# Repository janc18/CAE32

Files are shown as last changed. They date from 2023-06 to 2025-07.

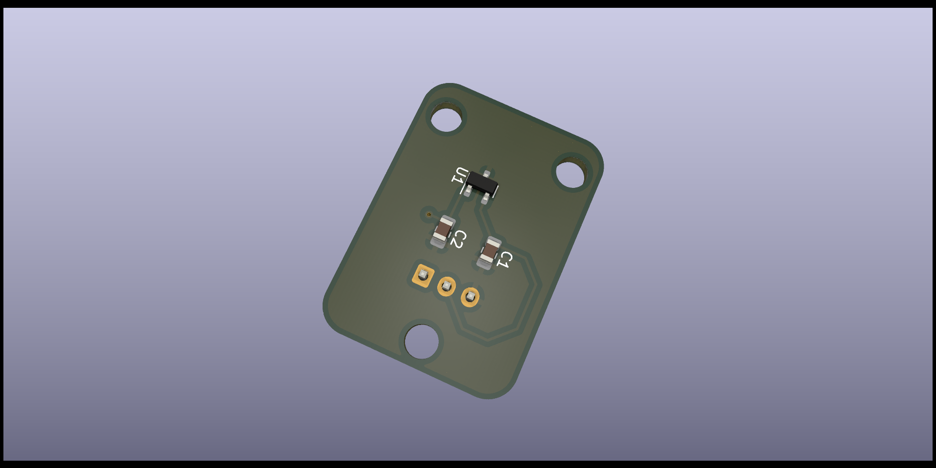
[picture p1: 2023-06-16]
Schematics/CAE32_PCB/Hall_PCB/hall_pcb.png

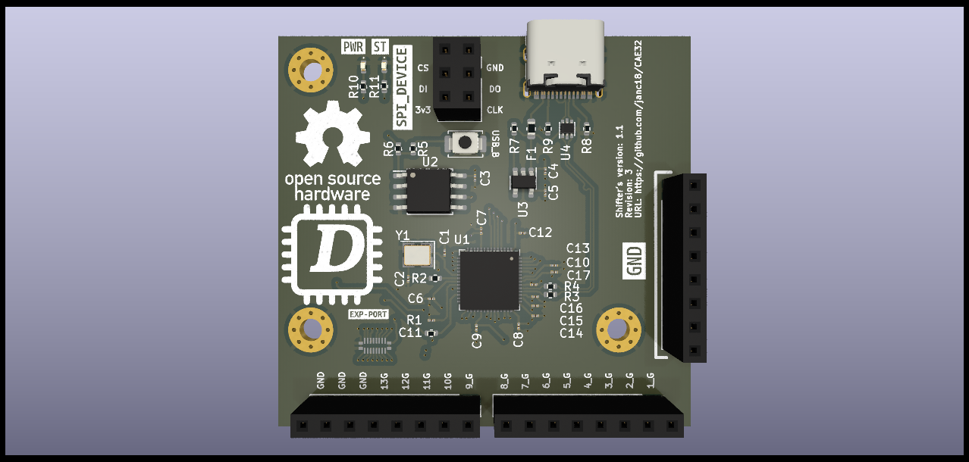
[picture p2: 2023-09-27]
Schematics/CAE32_PCB/Shifter/Shifter.png

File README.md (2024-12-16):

# CAE32

CAE32 is a project for building and developing all stages of a gaming wheel for PC, specifically for the GNU/Linux operating system.

If you want to contribute, please read the [CONTRIBUTING-english.md](./docs/CONTRIBUTING-english.md) file.

Si tu quieres contribuir, por favor lee el documento [CONTRIBUTING.md](./CONTRIBUTING.md)  

## Overall current status

Developing the UML diagram of the whole system

### PCBs







### Firmware

Working on the development of the UML diagram for the pedals  firmware

### Software

Needed the improvement of compilation and flags for the user interface

## The stages include:

* PCB Design
* Firmware
* Driver (Kernel module if necessary)
* Configuration and calibration through a graphical user interface (GTK-3)
* Design of mechanisms for pedals, gear lever, and wheel
* Power PCB design for feedback motor control (FFB)

### PCB Sponsored by PCBWay



The PCB quality is excellent, the contact with the support service is good, they responded very quickly in the case of any issue, 
and it has a good PCB finish using the STM assembly service,  all the IC pads are correctly soldered. Overall, the total cost of 5 PCBs 
and 2 PCBs with the assembly service is a very accessible, so I will keep using PCBWAY to build the next PCB iterations

[PCBWay Webpage](https://www.pcbway.com/)

## Programming Frameworks and Tools

* Espressif (ESP-IDF)
* STM32CubeIDE
* STM32CubeProgrammer

### User Interface

The interface is developed with the GTK 3 framework, which will allow configurations such as:

* Visualization of data graphically and textually (console)
* Transmission type (Manual, Automatic, Sequential, custom) **Natively**
* Pedal limits, sensitivity
* Pedal type
  * Analog input (Potentiometer, Hall effect, and load cell)
  * SPI, I2C input (Custom sensor)
* Firmware update

## How to compile the project

1. Install all the dependencies
```bash
sudo apt install cmake make gcc pkgconf libevdev-dev libgtk-3-dev libgtk-3-0 libgtest-dev g++
```

2. Run the script to check if all the dependencies was successfully installed
```bash
./Source_code/checking_dependency.sh
```
3. Execute the Makefile to build the graphic interface and the unit tests
```sh
make -C Source_code/
```

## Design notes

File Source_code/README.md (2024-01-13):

# Code // Codigo

In this folder, you can find the entire project code, which can be built by executing:

```sh 
make
```

*Now, a brief explanation of the files and folder content*

## config_file

File necessary to build all the documentation using the _Sphinx_ programm

## checking_dependency.sh 

A small bash script to check if all the dependencies are already installed, in case
someone isn't installed, it will print what is missing.

## Shared_libraries/

Files shared between the Firmare, TESTs, and Device_simulation folders for quick 
access and modifications.

## Desktop_files/

A bash script to execute when the GUI is select in the system menu

## Firmare/

Firmware for the modules(Pedals, shifter and steering wheel) and main board.

## Interfaz_grafica/

GUI(GTK) Source code 

## TESTs/

GUI and Device simulation unit tests

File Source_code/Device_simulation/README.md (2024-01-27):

# Device Simulation

In this section, you will find the resources required to build executables for simulating hardware.

# Steps to build a joystick simulation device

1. Create a build directory at src/
```sh
mkdir src/build 
```
2. Move to that directory
```sh
cd src/build
```

3. Build executable
```sh 
cmake ..
make
```

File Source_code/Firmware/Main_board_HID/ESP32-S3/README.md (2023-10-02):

# ESP32-S3
This is the source code for the main microcontroller, and it performs the following tasks:

- Communication with the host (PC), connecting via a USB cable and appearing in the system as an HID device (Joystick).

- Collection of all data from the modules, such as their position and status, through SPI communication.

- Firmware updates for modules via SPI, thus avoiding the use of firmware programmers for the module.

## Steps for Building the Project (in case you're not using the Docker container)

1. Install ESP-IDF.

2. In this directory, execute the following commands:

```sh
get-idf
idf.py build
```

3. Upload the new firmware.

## SPI Register for each module

### Pedals

|Command (HEX)|Name|Detalles|
|-|-|-|
|0x01|VERSION|Installed Firmware Version|
|0x02|CONFIG_RESOLUTION|Configure ADC Resolution|
|0x03|ACCE|Accelerator Value|
|0x04|BRAKE|Brake Value|
|0x05|CLUTCH|Clutch Value|
|0x06|STATUS|Error Status|

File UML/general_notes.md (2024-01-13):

# Change log PCB Pedals

## Issues
* Fix silkscreen text at UART port TX->RX RX->TX *Done*
* Change diameter pcb holes for M3 *Done*
* Route correctly the boot and reset buttons, and search for a small factor buttons *Done*
* Change communication connectors for a FCP connector *Done*
* Round pcb corners *Done*
* Change the female headers for block connectors or quick access connectors(Changed to screw terminals) *Done*
* The IC ADC require extra components at his inputs(added low pass filters) *Done*

## PCB Testing behavior

- Check the noise and data acquisition time without a single pole filter

## TDD(Test Driven Development)

To know if the GUI it's working correctly, one way, can be tested with the use of a virtual device than can be created with the 
uhid library for the linux system, the functionalities that could be tested will be the next:

- Device detection (Connection)
- Device descriptor
- Visual representation (axis and steering wheel)
- Emulation of device console(sending and reciving data for configuration behavior)

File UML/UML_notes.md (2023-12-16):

# Packages

- UI
  - UI Updater
  - Status console
  - Firmware Updater::Stm cube programmer
  - Data values display
  - Configuration pcb values(soft stops, hard stops, sensibility, etc)

- Devices configuration
    - Steering wheel configuration
      - Serial terminal
    - Pedals configuration
      - Serial terminal
    - Shifter configuration 
      - Serial terminal
  
_With the Serial terminal it's posible to send values witout the necessity of firmware update_

- Hardware(PCBs)
    - Steering wheel
    - Pedals
    - Shifter

# Use cases diagram

- Hardware
- USB
- HID
- Game
- UI

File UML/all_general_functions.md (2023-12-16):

# General functions overview 

## GUI(GTK)

* Representation in real time of the input (pedals, shifter, etc.) generated by the user 
* Easy configuration of the devices
* Console for displaying information
* Firmware update and upload
* GUI update
* Verification of software dependencies (STM32CubeProgrammer) bin path selection
* Information about the program

## Pedals 

*Note 1: for some cases is implied to use a serial terminal*

*Note 2: some function depends of other sources like config files founded at PC(Linux system)*

- Get analog readings
  - Serial data communication with ADC chip
    - initial IC configuration (Resolution, speed, one shot,etc)
    - *Get data*
  - getting the data stream from the load cell IC 
    - Configure a pwm channel to generate the clock signal
    - *Get data*

- Compact or mergue all the data for usb HID protocol
  * After the analog readings send the usb data stream

- Load pre-configuration using the dip switch 
  * if it's not posible to load a new configuration to the pcb because it's imposible to access to the GUI it will have some profiles pre-loaded

- HID device descriptor
  - 3 to 11 channels
  - 14 bits each
  - serial terminal for pcb status and configuration
  - bit stream for configuration *optional*

- PCB Status
  - Check if ICs ADC and load cell function correctly _serial terminal_
  - show the status with the serial terminal and leds

- apply filter to any analog signal
  * before sending the data, it will apply a function to modify the raw values to apply a filter(low filter, high filter)
  *Note: this will be generated by the GUI and sended by the serial terminal*

- Calibration functions

  _Note 1: This process will be guide graphical by the GUI, if the GUI isn't available then can be Configure with the serial terminal_
  
  - choose the start and stop position
  - sensibility
  - select what pedal correspond to certain input

- UI config file (.txt | .config | .cae32) *Founded in the Linux system*

- add function to check system stability (low resorces or not enough speed, etc)

- all task or functions need to return finish status (SUCCESS, ERROR, [custom errors messages])

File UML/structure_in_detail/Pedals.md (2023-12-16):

# Draft structure of functions 

This is a firmware draft of how can be develop the code for the pedals.

This file will include the posible functions, struct, enums that will be used for the UML diagram

## Tasks (FreeRTOS)

- StatusMonitorTask
- IcAdcReading
- LoadCellDataAdquisition
- SendingUsbPackage
- SerialTerminalInUsbData
- SerialTerminalOutUsbData
- ApplyAdcFilter
- ShowLedStatus
- LoadProfile (use an interruption in the case of any change at switches states)

## Functions
- SetConfigValues (set, top and low limits, inverted axis)
- GetConfigValues (get, top and low limits, inverted axis)
- LoadProfile (Load all the values from the ROM)
- CreateProfile
  - Save the limits and what function do every channel, example(ADC channel 1 its the brake,Load cell 1 is the clutch, etc.)
  - Depending of the dip switch state located at the pcb will save the already create profile in a different location to save until 7 profiles    
  - Save values at ROM
- ConfigUsbStream (depending of the profile select change the device descriptor)
- Reboot
- LimitsCalibration (With the GUI or serial terminal, pressing the pedal to define in real time the limits)
- ReadSwitchValue (Get the value depending of the 3 switch inputs) 
- ParserCommand (build a struct that can be used to modify values)  

## Enum

```c
typedef enum {
    TASK_SUCCESS,
    TASK_ERROR_GENERIC,
    TASK_ERROR_TIMEOUT
}TaskStatus;

typedef enum{
    INVALID_PARAMETER,

}err_t

typedef enum {
    ADC_CHANNEL_0,
    ADC_CHANNEL_1,
    ADC_CHANNEL_2,
    ADC_CHANNEL_3,
    ADC_CHANNEL_4,
    ADC_CHANNEL_5,
    ADC_CHANNEL_6,
    ADC_CHANNEL_7,
    LC_CHANNEL_1,
    LC_CHANNEL_2,
    LC_CHANNEL_3,
}Channel

```

## Structs

```c
typedef struct{
  void *funtion-to-execute-in-case-of-error;
  void *generic-function-to-text-through-serial-console;
  uint32 RetryCount;
  
}StatusTask;

/*
- The value correspond to the channel to use 
- Example
    - Clutch channel ADC 3 = Clutch=ADC_CHANNEL_3;
    - Throttle Load cell 1 = Throttle=LC_CHANNEL_1;
    - The channels than don't be use its value is = -1
    - All customs channels without use = Custom_0 = -1;
*/

typedef struct{
    char Throttle;
    char Clutch;
    char Brake;
    char Custom_0;
    char Custom_1;
    char Custom_2;
    char Custom_3;
    char Custom_4;
    char Custom_5;
    char Custom_6;
    char Custom_7;
    char Custom_8;
    char Custom_9;
}ChannelFunction;

typedef struct{

}LowPassFilterValues;

typedef struct{
    uint16 Low;
    uint16 Top;
    bool inverted;
}HardwareConfig

```

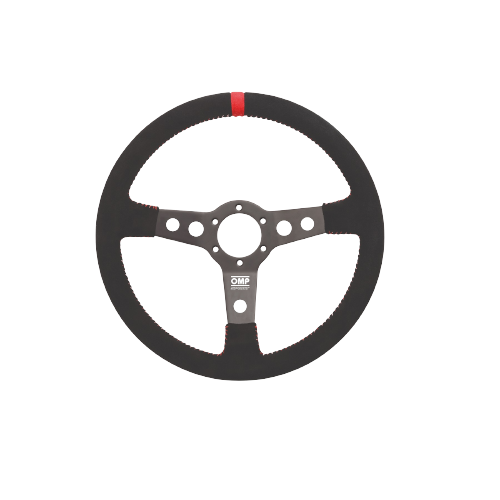
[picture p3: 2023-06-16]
Source_code/Interfaz_grafica/Interfaz_gtk/src_images/Volante3.png

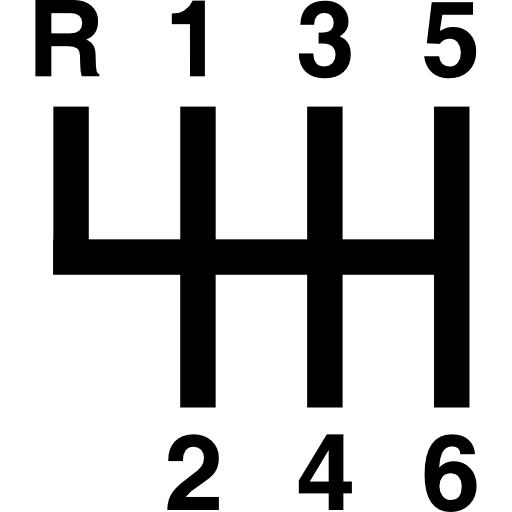
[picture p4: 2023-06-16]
Source_code/Interfaz_grafica/Interfaz_gtk/src_images/H.png

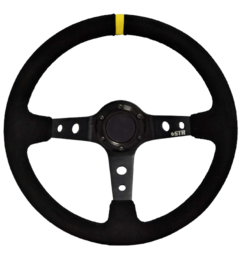
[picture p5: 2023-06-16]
Source_code/Interfaz_grafica/Interfaz_gtk/src_images/Volante3-1.png

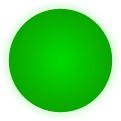
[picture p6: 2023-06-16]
Source_code/Interfaz_grafica/Interfaz_gtk/src_images/bitmap.png

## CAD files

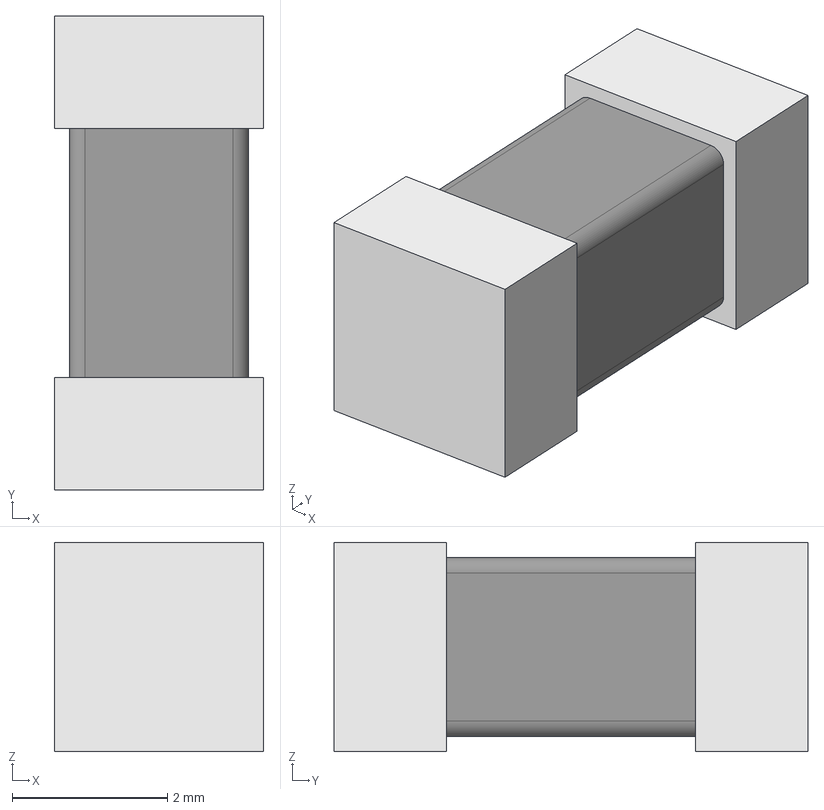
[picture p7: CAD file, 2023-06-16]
Schematics/CAE32_PCB/Disenos_de_componentes_electricos/Modelos3d/Freecad/fusible.FCStd
2.69 x 6.10 x 2.69 mm

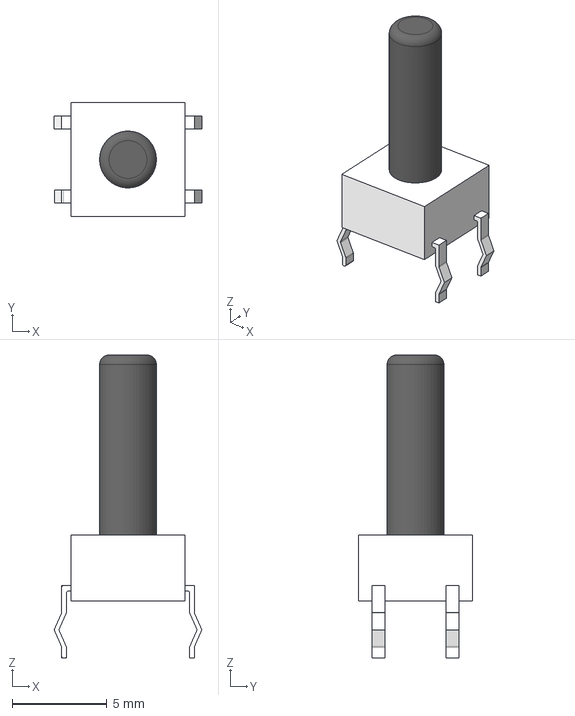
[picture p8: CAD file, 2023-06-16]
Schematics/CAE32_PCB/Pedals/3d Models/TS-1095PD-A16B2-D2.FCStd
7.80 x 6.00 x 16.0 mm

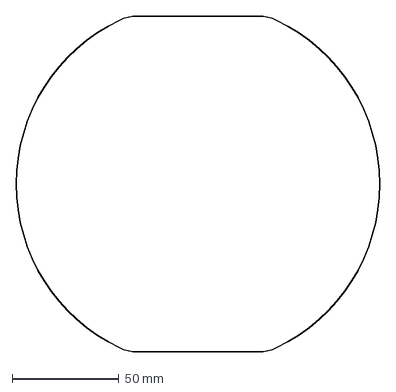
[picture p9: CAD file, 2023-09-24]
Schematics/CAE32_PCB/Steering_Wheel_FFB/3D_models/simcube.dxf
170.0 x 157.1 mm

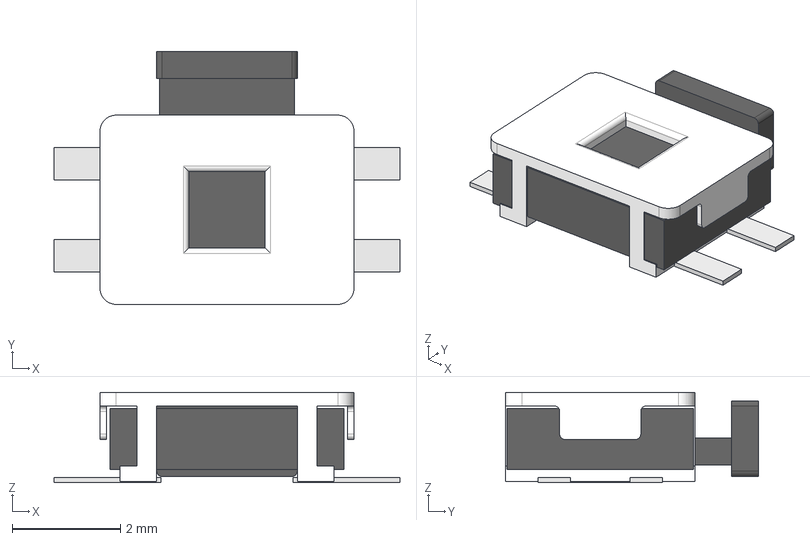
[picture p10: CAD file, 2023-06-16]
Schematics/Modelos_3D_Componentes_electricos/EVQPUM02K.FCStd
6.40 x 4.68 x 1.67 mm

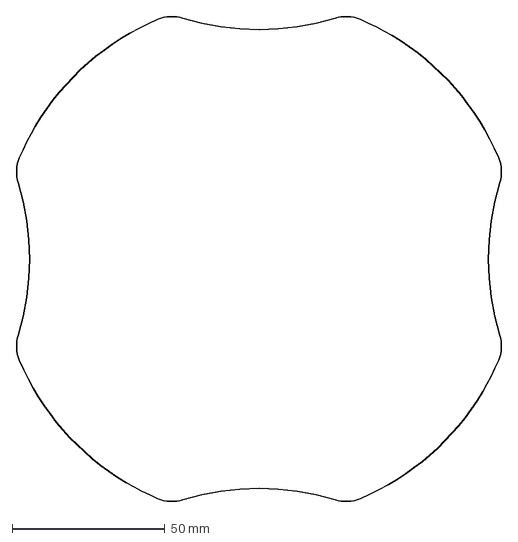
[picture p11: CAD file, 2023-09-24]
Schematics/CAE32_PCB/Steering_Wheel_FFB/3D_models/cutOutPcb-Shape2DView.dxf
158.6 x 158.6 mm

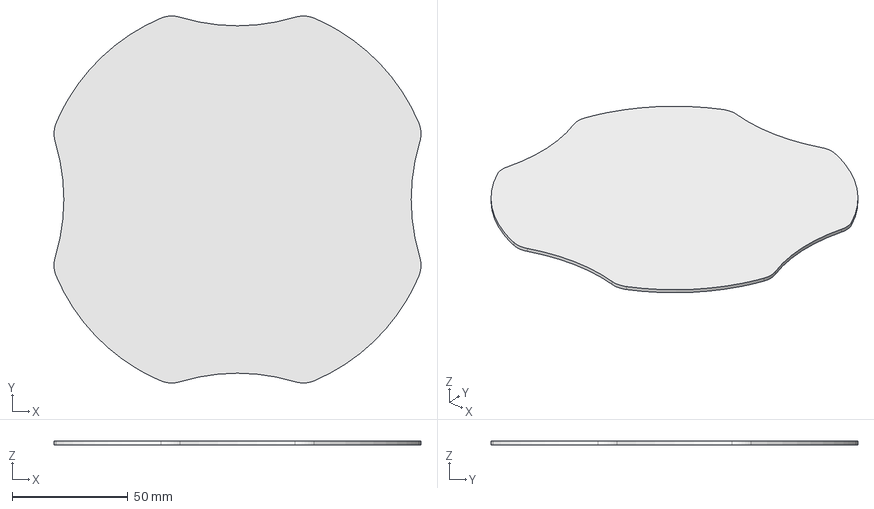
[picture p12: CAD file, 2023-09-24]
Schematics/CAE32_PCB/Steering_Wheel_FFB/3D_models/cutOutPcb.FCStd
158.5 x 158.5 x 1.60 mm

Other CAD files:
Schematics/CAE32_PCB/Hall_PCB/CutPcbLayout/edges.FCStd
Schematics/CAE32_PCB/Pedals/CutPcbLayout/layout.FCStd
Schematics/CAE32_PCB/Pedals/3d Models/TS-1095PD-A16B2-D2-Part.step
Schematics/Modelos_3D_Componentes_electricos/EVQPUM02K-Part.step

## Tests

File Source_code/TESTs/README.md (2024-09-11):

# Unit Tests

## Device descriptor tester

At the folder ```device_descriptor``` is the source code to check if the device descriptor
is correctly configured.

The executable can be found at ```device_descriptor/build/bin``` this is compile automatically
when you build the whole project (**Instructions at the main README**), 

## How it works
This executable needs an input file with all the information about the device to search, an 
example of this file can be found at ```device_descriptor/build/bin```, it requires a sudo 
permission to read the incoming data from the device.

This program is paired with another program, that program create a virtual device that 
simulates inputs and it's verify with the input file give (**Example at device_descriptor/build/bin**)

## TODO

- [ ] Input analysis (Virtual Device)
    - [x] Get the number of the Events
    - [ ] Allocate memory for each Event
    - [ ] Add each value to an array of Event
    - [ ] Get the step increment
    - [ ] Get from file the actuation range
    - [ ] Create a log than can be saved in a file
    - [ ] 

- [ ] Free resources (memory) when the device is desconnected
    - [ ] Know whe the device was disconnected

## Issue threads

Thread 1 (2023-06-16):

Crear un archivo docker

janc18, 2023-06-16:
Para que sea más sencillo realizar la construcción y pruebas unitarias, lo conveniente es crear un contenedor con todas las dependencias necesarias.

Para compilar

- Interfaz de usuario(GTK3)
- Firmware (ESP-IDF y "STM en el caso de que sea posible")

janc18, 2023-06-17:
Se añadió un archivo Docker con base de Debian Bullseye, referente a la construcción del firmware usando ESP-IDF, no es necesario debido a qué ya cuenta con una imagen oficial de Docker

Closed 2023-06-17.

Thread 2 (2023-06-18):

Crear tests para GUI y dispositivo

janc18, 2023-06-18:
Como buen software en desarrollo requiere de pruebas.

Para probar la GUI y el dispositivo HID, es posible crear un dispositivo virtual HID conocido como modulo uinput,  [aquí](https://github.com/janc18/CAE32/blob/main/Codigo/Device_simulation/src/uhid-HID.c) se encuentra un ejemplo.

Lo ideal es crear un Makefile, donde ejecute diferentes pruebas.

También sera necesario crear una versión de debug de la GUI, he incluso logs

Closed 2023-09-30.

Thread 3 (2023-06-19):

Calcular consumo de PCB

janc18, 2023-06-19:
Revisar en la hoja de datos de cada componte (IC's) su consumo(mAh) y anotarlo en el esquema eléctrico

janc18, 2023-06-20:
El consumo aproximado es:
|Componente|Consumo|Cantidad|
|-|-|-|
|MCU|120 mA|1|
|REF3033|50uA|1|
|ADC128S102|3.1mA|1|
|HX711|1500ua|3|

**Consumo total en primera revisión:128mA**

HUANGJIN169, 2023-09-01:
Very good. When will the direct drive PCB be updated?

janc18, 2023-09-03:
Hi, I haven't started yet the development of the Direct drive PCB, I just finished the Pedals PCB version 2 about two moths ago, but i haven't tested it yet, I need to get the PCB manufactured, assembly and firmware programming but I can't do it right now, tomorrow i will update the CAE32 docs with an English version, for now please give a check:https://cae32-docs.readthedocs.io/es/latest/

janc18, 2023-09-03:
Please review de Documentation,which is now available English.

HUANGJIN169, 2023-09-03:
Ok, thank you for your reply. I also look forward to your direct drive PCB

HUANGJIN169, 2023-09-13:
Hello, how can I contact you, such as Facebook or Twitter and no China WeChat?

janc18, 2023-09-13:
Hi @HUANGJIN169 , you can contact me through Discord. This is my username:eling.
But if you can't use Discord I can create a Twitter account

janc18, 2023-09-14:
Twitter account: ElingJAg

HUANGJIN169, 2023-09-15:
You can add my friend through Discord. My user name is:simracingos#6659

Closed 2023-09-04.

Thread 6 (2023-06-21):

Añadir serigrafía a la PCB

janc18, 2023-06-21:
Agregar la siguiente serigrafía a la PCB

* Símbolos de open hardware

* Easter egg

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

* Datos de PCB (URL de REPO, número de revisión, versión de PCB)

* Añadir nombres de puertos correspondientes (UART, CAN, SPI, etc.)

janc18, 2023-06-22:
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

Closed 2023-06-22.

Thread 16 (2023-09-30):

Redesign the Shifter PCB

janc18, 2023-09-30:
To meet standard features without incurring extra costs from the PCB manufacturer

HUANGJIN169, 2023-09-30:
very good

janc18, 2023-10-01:
# Change-log *Shifter_PCB_v1.2.1*

- Replace the Pin Headers for FCP connectors
- Changed via diameter from 0.15 to 0.3mm
- Changed BOOT button position
- Replace all the GND Pin Headers for just 3 Pin Sockets

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

Closed 2023-10-01.

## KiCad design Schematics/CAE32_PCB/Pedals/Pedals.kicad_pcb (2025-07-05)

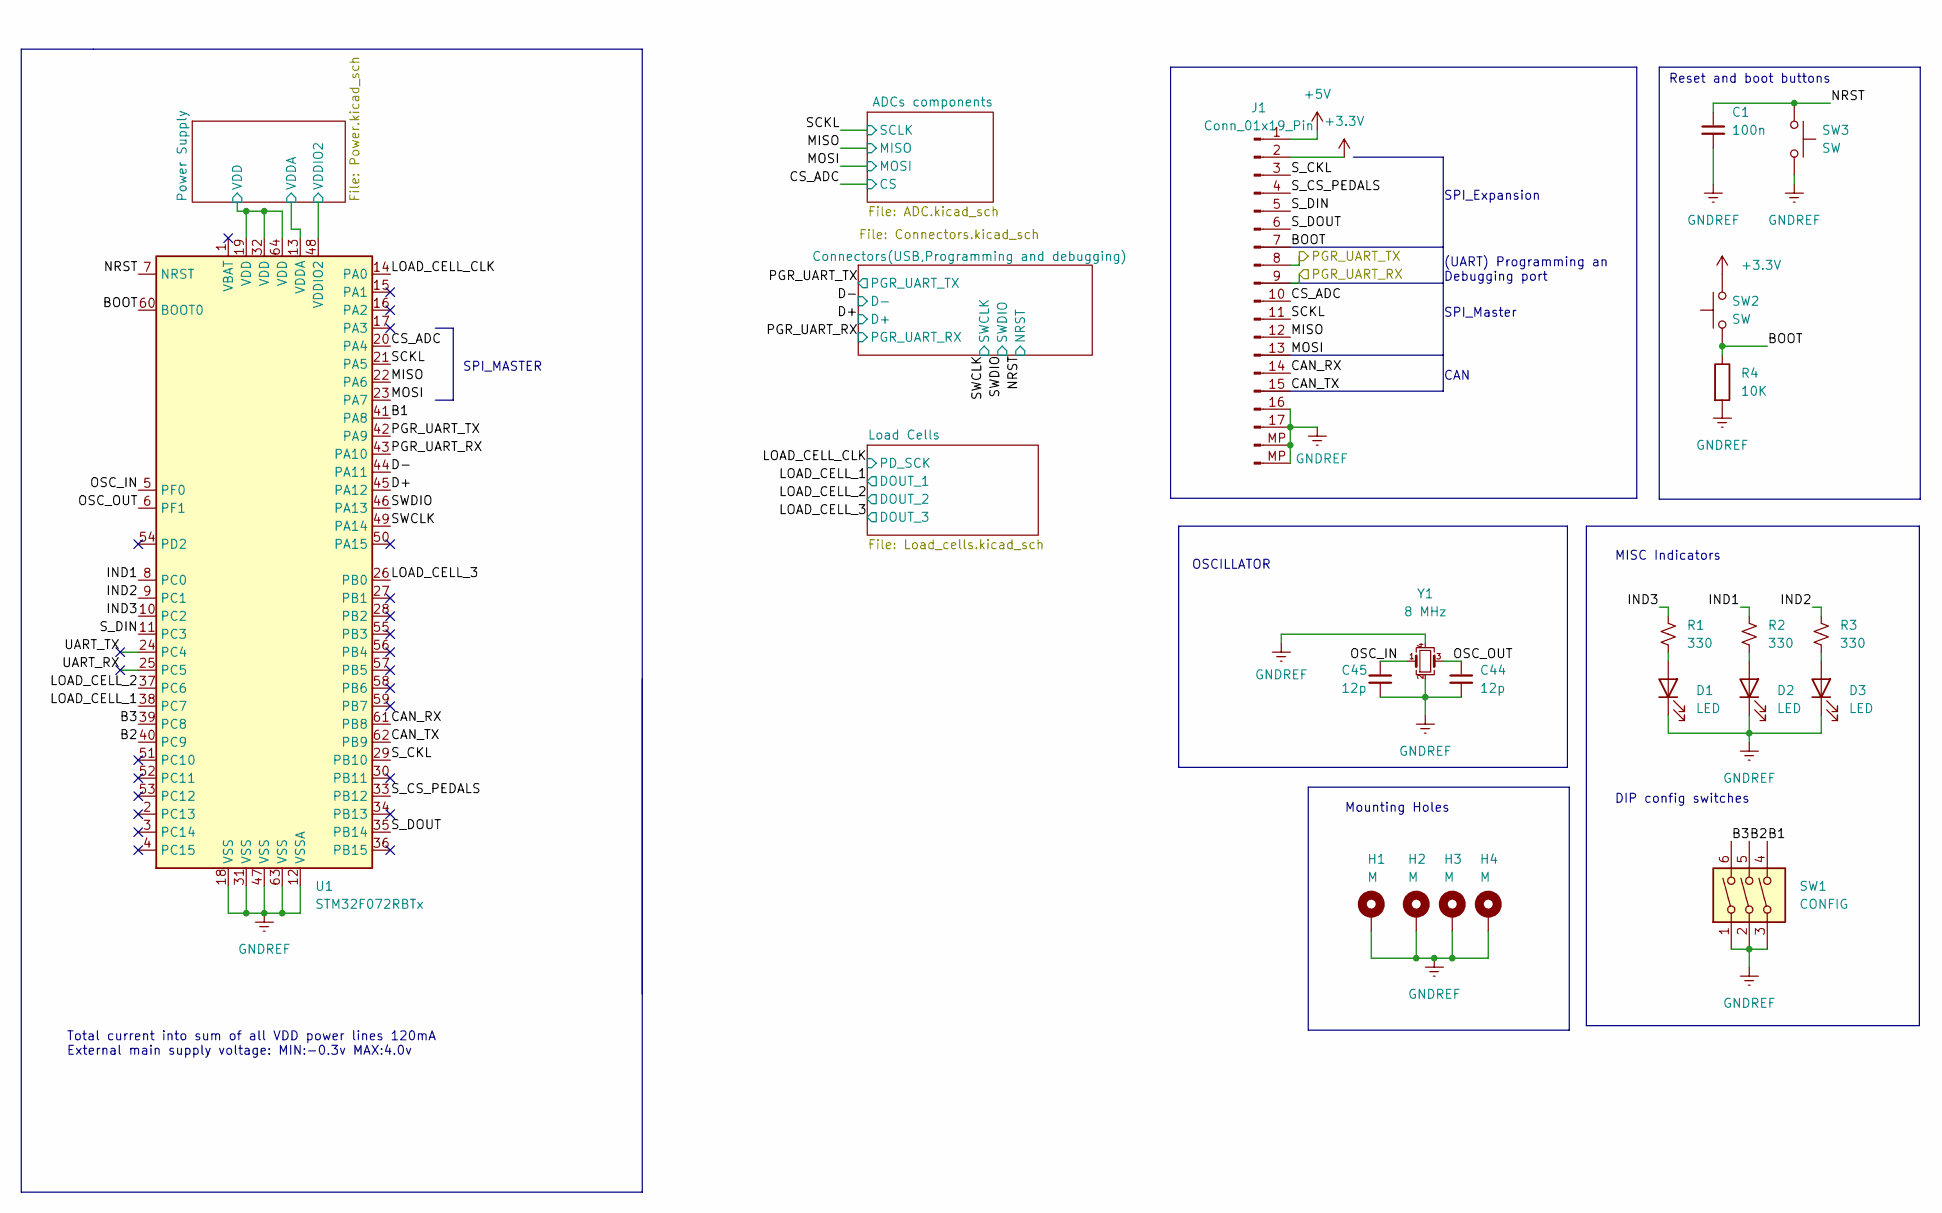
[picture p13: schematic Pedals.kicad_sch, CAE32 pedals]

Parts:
C1: 100n; C_0603_1608Metric; LCSC_PART C66501
C44, C45: 12p; C_0603_1608Metric; LCSC_PART C882527
D1, D2, D3: LED; LED_0805_2012Metric; LCSC_PART C965815
H1, H2, H3, H4: M; MountingHole_3.2mm_M3_DIN965_Pad_TopBottom
J1: Conn_01x19_Pin; TE_1-84953-7_1x17-1MP_P1.0mm_Horizontal; LCSC_PART C500176
R1, R2, R3: 330; R_0603_1608Metric; LCSC_PART C21190
R4: 10K; R_0603_1608Metric; LCSC_PART C25804
SW1: CONFIG; SW_DIP_SPSTx03_Slide_KingTek_DSHP03TJ_W5.25mm_P1.27mm_JPin; LCSC_PART C5289932
SW2, SW3: SW; SW_SPST_TL3342; LCSC_PART C2886897
U1: STM32F072RBTx; LQFP-64_10x10mm_P0.5mm; LCSC_PART C46046
Y1: 8 MHz; Crystal_SMD_3225-4Pin_3.2x2.5mm; LCSC_PART C2682775

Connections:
+3.3V: J1.2, SW2.2, U1.13 (VDDA), U1.19 (VDD), U1.32 (VDD), U1.48 (VDDIO2), U1.64 (VDD); also elsewhere on the board
+5V: J1.1; also elsewhere on the board
/B1: SW1.4, U1.41 (PA8)
/B2: SW1.5, U1.40 (PC9)
/B3: SW1.6, U1.39 (PC8)
/BOOT: J1.7, R4.1, SW2.1, U1.60 (BOOT0)
/CAN_RX: J1.14, U1.61 (PB8)
/CAN_TX: J1.15, U1.62 (PB9)
/CS_ADC: J1.10, U1.20 (PA4); also elsewhere on the board
/D+: U1.45 (PA12); also elsewhere on the board
/D-: U1.44 (PA11); also elsewhere on the board
/IND1: R2.1, U1.8 (PC0)
/IND2: R3.1, U1.9 (PC1)
/IND3: R1.1, U1.10 (PC2)
/LOAD_CELL_1: U1.38 (PC7); also elsewhere on the board
/LOAD_CELL_2: U1.37 (PC6); also elsewhere on the board
/LOAD_CELL_3: U1.26 (PB0); also elsewhere on the board
/LOAD_CELL_CLK: U1.14 (PA0); also elsewhere on the board
/MISO: J1.12, U1.22 (PA6); also elsewhere on the board
/MOSI: J1.13, U1.23 (PA7); also elsewhere on the board
/NRST: C1.1, SW3.1, U1.7 (NRST); also elsewhere on the board
/OSC_IN: C45.1, U1.5 (PF0), Y1.1
/OSC_OUT: C44.1, U1.6 (PF1), Y1.3
/PGR_UART_RX: J1.9, U1.43 (PA10)
/PGR_UART_TX: J1.8, U1.42 (PA9)
/SCKL: J1.11, U1.21 (PA5); also elsewhere on the board
/SWCLK: U1.49 (PA14); also elsewhere on the board
/SWDIO: U1.46 (PA13); also elsewhere on the board
/S_CKL: J1.3, U1.29 (PB10)
/S_CS_PEDALS: J1.4, U1.33 (PB12)
/S_DIN: J1.5, U1.11 (PC3)
/S_DOUT: J1.6, U1.35 (PB14)
/UART_RX: U1.25 (PC5)
/UART_TX: U1.24 (PC4)
GNDREF: C1.2, C44.2, C45.2, D1.1 (K), D2.1 (K), D3.1 (K), H1.1, H2.1, H3.1, H4.1, J1.16, J1.17, J1.MP, R4.2, SW1.1, SW1.2, SW1.3, SW3.2, U1.12 (VSSA), U1.18 (VSS), U1.31 (VSS), U1.47 (VSS), U1.63 (VSS), Y1.2, Y1.4; also elsewhere on the board
unnamed: D1.2 (A), R1.2
unnamed: D2.2 (A), R2.2
unnamed: D3.2 (A), R3.2

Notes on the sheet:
(UART) Programming an Debugging port
OSCILLATOR
CAN
SPI_MASTER
DIP config switches
SPI_Expansion
Mounting Holes
Total current into sum of all VDD power lines 120mA External main supply voltage: MIN:-0.3v MAX:4.0v
MISC Indicators
SPI_Master
Reset and boot buttons

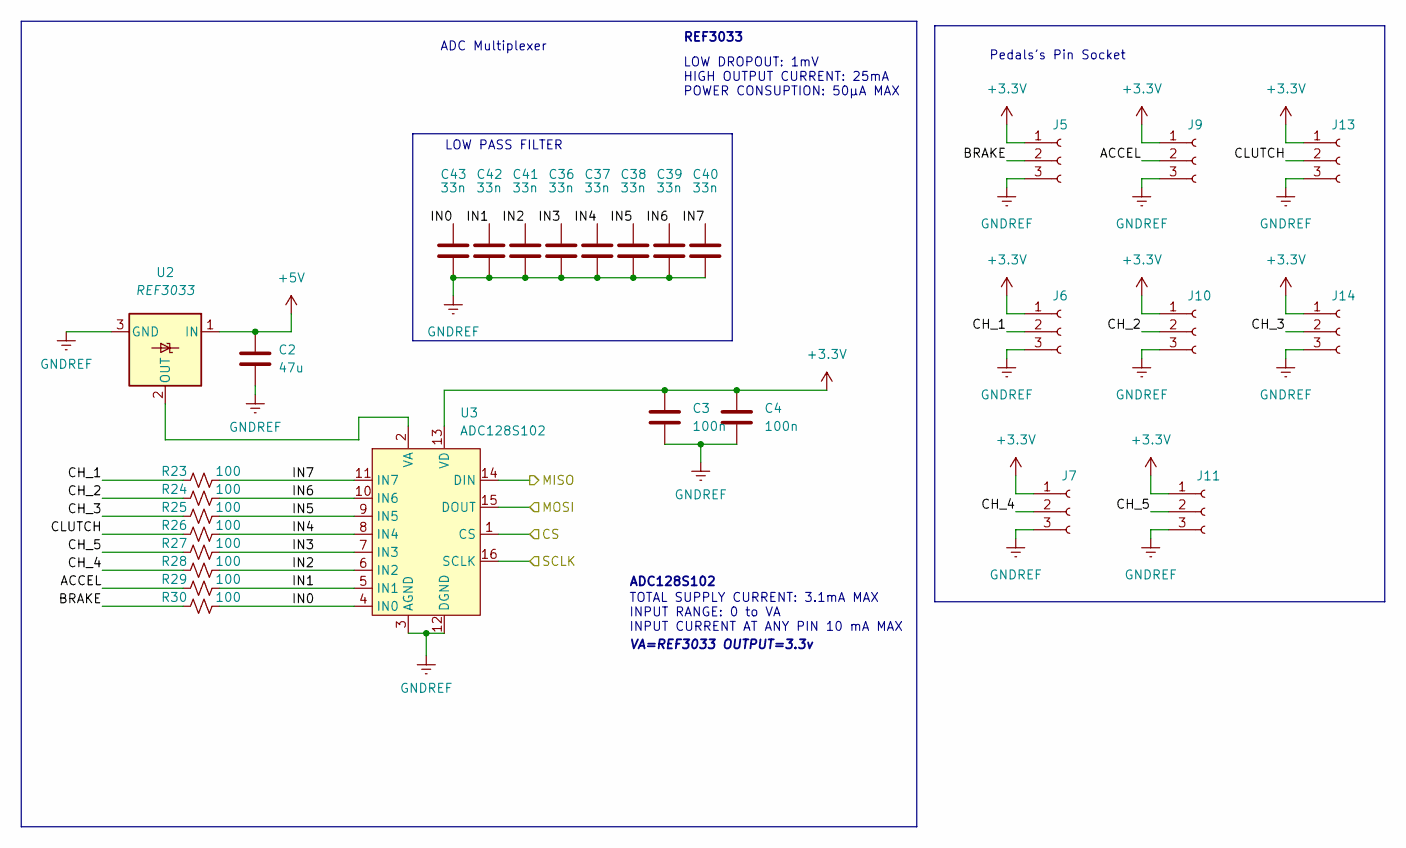
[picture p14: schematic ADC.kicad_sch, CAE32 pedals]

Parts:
C2: 47u; C_0603_1608Metric; LCSC_PART C140782
C3, C4: 100n; C_0603_1608Metric; LCSC_PART C66501
C36, C37, C38, C39, C40, C41, C42, C43: 33n; C_0603_1608Metric; LCSC_PART C21117
J5, J6, J7, J9, J10, J11, J13, J14: Conn_01x03_Female; PinHeader_1x03_P2.54mm_Vertical; LCSC_PART C6332196
R23, R24, R25, R26, R27, R28, R29, R30: 100; R_0603_1608Metric; LCSC_PART C25201
U2: REF3033; SOT-23; LCSC_PART C36658
U3: ADC128S102; TSSOP-16_4.4x5mm_P0.65mm

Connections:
+3.3V: C3.1, C4.1, J5.1, J6.1, J7.1, J9.1, J10.1, J11.1, J13.1, J14.1, U3.13 (VD); also elsewhere on the board
+5V: C2.1, U2.1 (IN); also elsewhere on the board
/ADCs components/ACCEL: J9.2, R29.1
/ADCs components/BRAKE: J5.2, R30.1
/ADCs components/CH_1: J6.2, R23.1
/ADCs components/CH_2: J10.2, R24.1
/ADCs components/CH_3: J14.2, R25.1
/ADCs components/CH_4: J7.2, R28.1
/ADCs components/CH_5: J11.2, R27.1
/ADCs components/CLUTCH: J13.2, R26.1
/ADCs components/IN0: C43.1, R30.2, U3.4 (IN0)
/ADCs components/IN1: C42.1, R29.2, U3.5 (IN1)
/ADCs components/IN2: C41.1, R28.2, U3.6 (IN2)
/ADCs components/IN3: C36.1, R27.2, U3.7 (IN3)
/ADCs components/IN4: C37.1, R26.2, U3.8 (IN4)
/ADCs components/IN5: C38.1, R25.2, U3.9 (IN5)
/ADCs components/IN6: C39.1, R24.2, U3.10 (IN6)
/ADCs components/IN7: C40.1, R23.2, U3.11 (IN7)
/CS_ADC: U3.1 (CS); also elsewhere on the board
/MISO: U3.14 (DIN); also elsewhere on the board
/MOSI: U3.15 (DOUT); also elsewhere on the board
/SCKL: U3.16 (SCLK); also elsewhere on the board
GNDREF: C2.2, C3.2, C4.2, C36.2, C37.2, C38.2, C39.2, C40.2, C41.2, C42.2, C43.2, J5.3, J6.3, J7.3, J9.3, J10.3, J11.3, J13.3, J14.3, U2.3 (GND), U3.3 (AGND), U3.12 (DGND); also elsewhere on the board
unnamed: U2.2 (OUT), U3.2 (VA)

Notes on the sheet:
LOW DROPOUT: 1mV HIGH OUTPUT CURRENT: 25mA POWER CONSUPTION: 50μA MAX
ADC Multiplexer
VA=REF3033 OUTPUT=3.3v
ADC128S102
Pedals's Pin Socket
LOW PASS FILTER
REF3033
TOTAL SUPPLY CURRENT: 3.1mA MAX INPUT RANGE: 0 to VA INPUT CURRENT AT ANY PIN 10 mA MAX

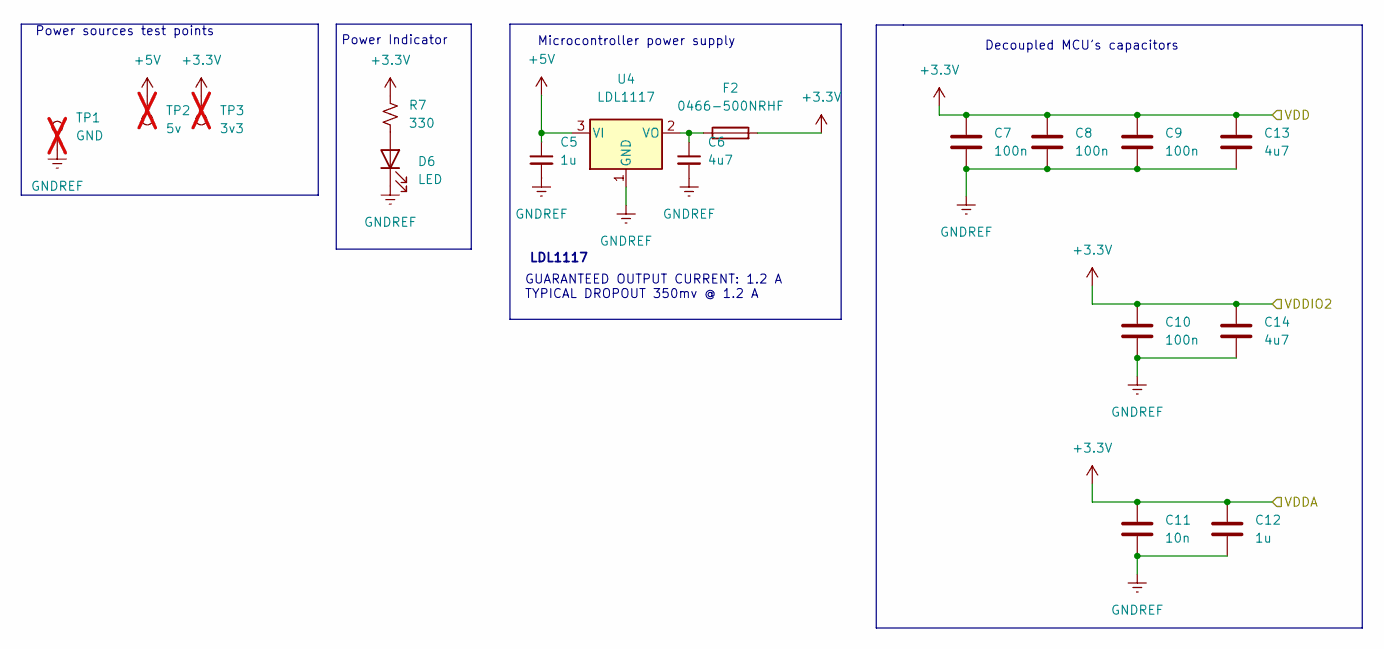
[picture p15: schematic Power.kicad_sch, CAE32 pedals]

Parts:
C5, C12: 1u; C_0603_1608Metric; LCSC_PART C1592
C6, C13, C14: 4u7; C_0603_1608Metric; LCSC_PART C1705
C7, C8, C9, C10: 100n; C_0603_1608Metric; LCSC_PART C66501
C11: 10n; C_0603_1608Metric; LCSC_PART C100042
D6: LED; LED_0805_2012Metric; LCSC_PART C965815
F2: 0466-500NRHF; Fuse_1206_3216Metric; LCSC_PART C151133
R7: 330; R_0603_1608Metric; LCSC_PART C21190
TP1: GND; TestPoint_Pad_D1.0mm; not fitted
TP2: 5v; TestPoint_Pad_D1.0mm; not fitted
TP3: 3v3; TestPoint_Pad_D1.0mm; not fitted
U4: LDL1117; SOT-223-3_TabPin2; LCSC_PART C2798214

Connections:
+3.3V: C7.1, C8.1, C9.1, C10.1, C11.1, C12.1, C13.1, C14.1, F2.2, R7.1, TP3.1; also elsewhere on the board
+5V: C5.1, TP2.1, U4.3 (VI); also elsewhere on the board
GNDREF: C5.2, C6.2, C7.2, C8.2, C9.2, C10.2, C11.2, C12.2, C13.2, C14.2, D6.1 (K), TP1.1, U4.1 (GND); also elsewhere on the board
unnamed: D6.2 (A), R7.2
unnamed: C6.1, F2.1, U4.2 (VO)

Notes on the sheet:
Decoupled MCU's capacitors
Power Indicator
GUARANTEED OUTPUT CURRENT: 1.2 A TYPICAL DROPOUT 350mv @ 1.2 A
Microcontroller power supply
Power sources test points
LDL1117

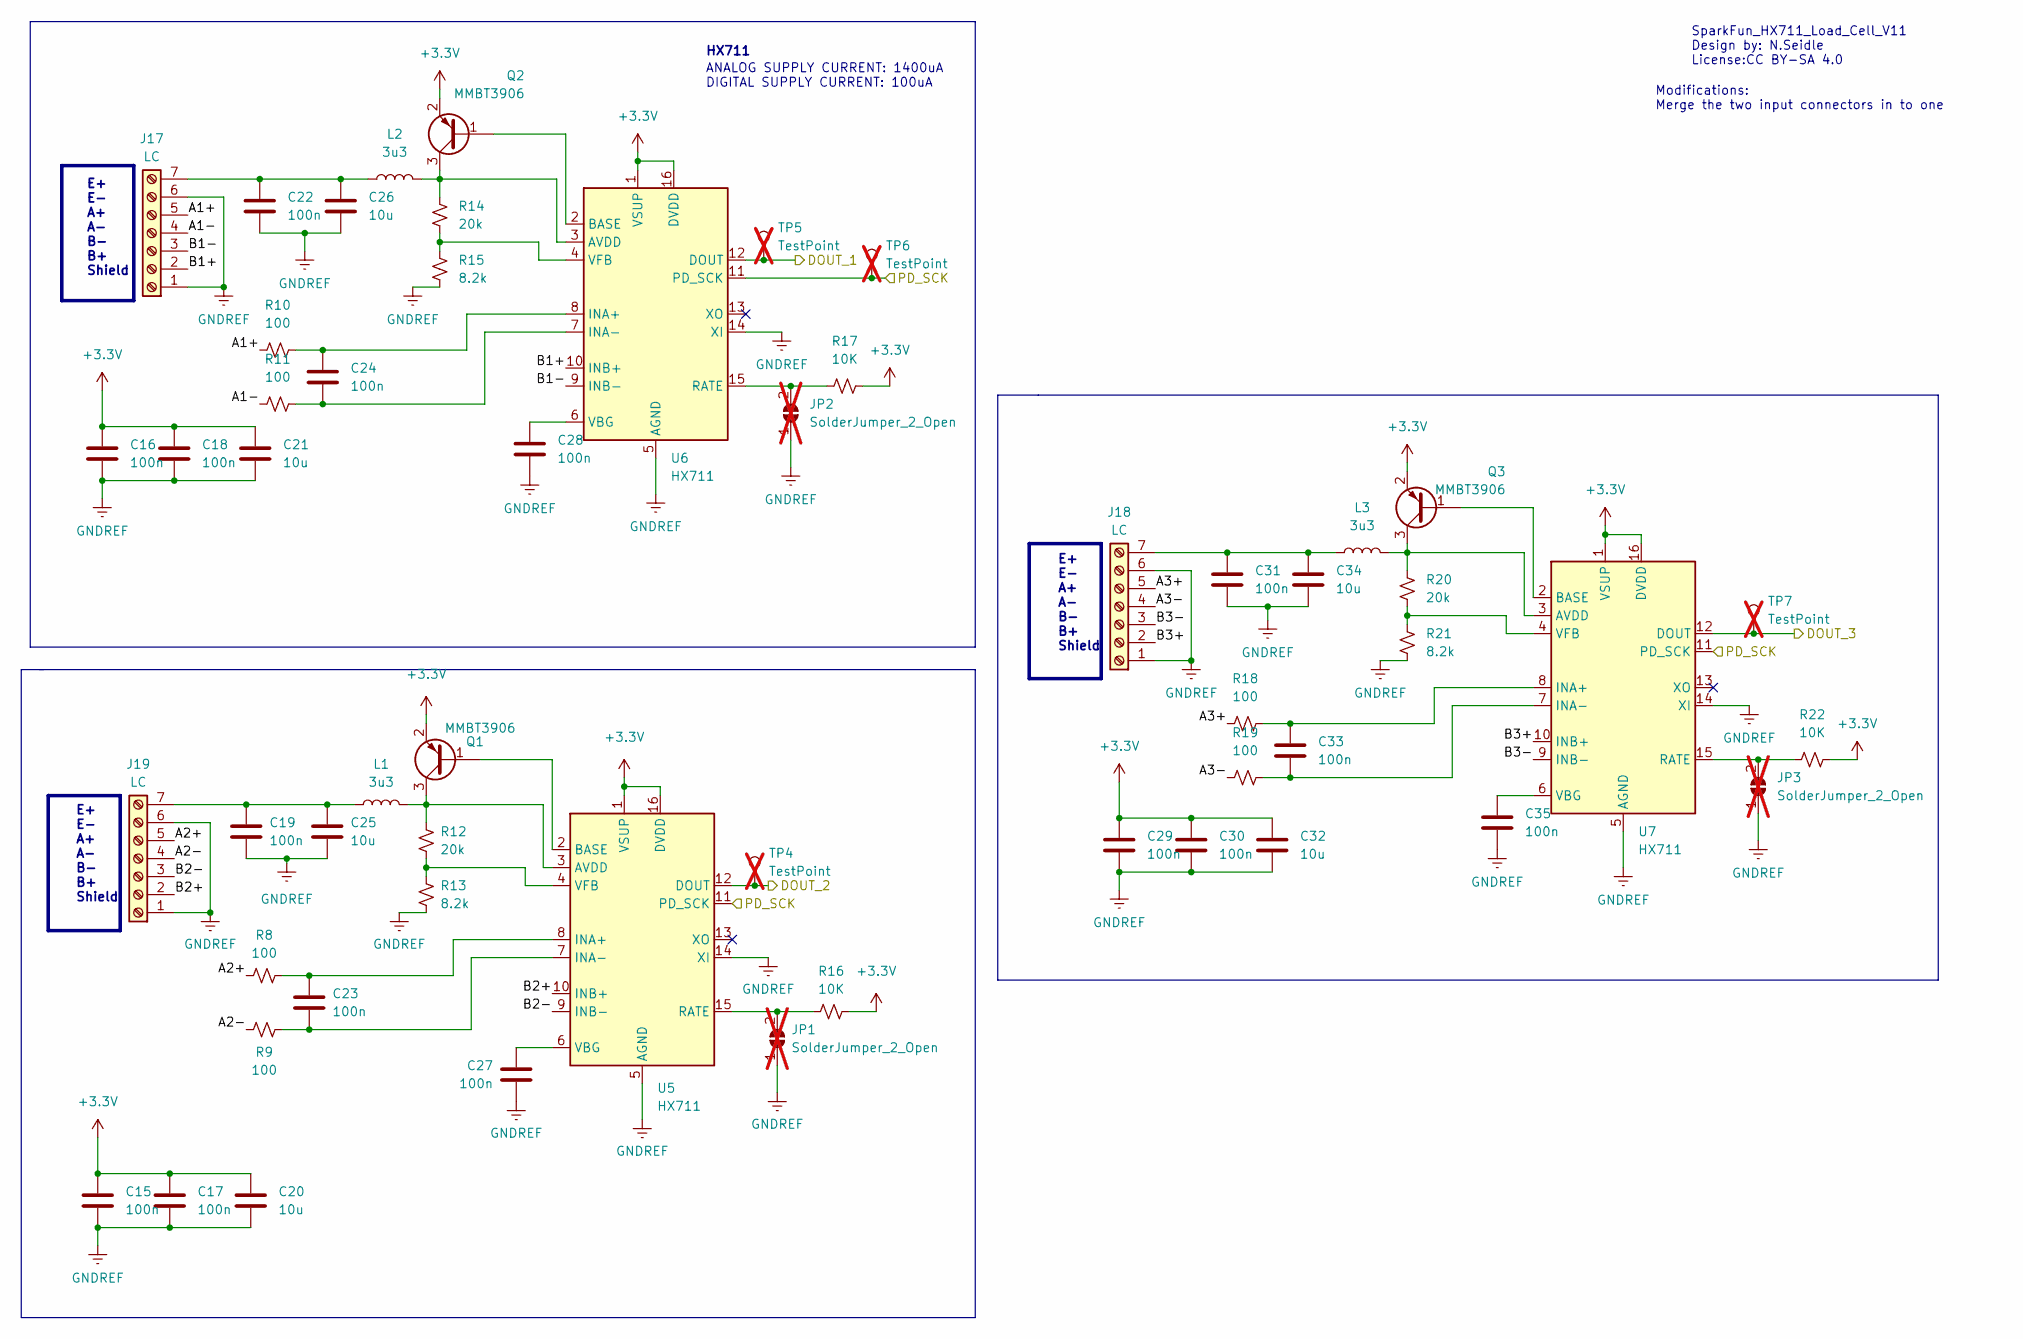
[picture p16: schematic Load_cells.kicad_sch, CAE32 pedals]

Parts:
C15, C16, C17, C18, C19, C22, C23, C24, C27, C28, C29, C30, C31, C33, C35: 100n; C_0603_1608Metric; LCSC_PART C66501
C20, C21, C25, C26, C32, C34: 10u; C_0603_1608Metric; LCSC_PART C1691
J17, J18, J19: LC; TerminalBlock_TE_282834-7_1x07_P2.54mm_Horizontal; LCSC_PART C915916
JP1, JP2, JP3: SolderJumper_2_Open; SolderJumper-2_P1.3mm_Open_RoundedPad1.0x1.5mm; not fitted
L1, L2, L3: 3u3; L_0402_1005Metric; LCSC_PART C84474
Q1, Q2, Q3: MMBT3906; SOT-23
R8, R9, R10, R11, R18, R19: 100; R_0603_1608Metric; LCSC_PART C25201
R12, R14, R20: 20k; R_0603_1608Metric; LCSC_PART C4184
R13, R15, R21: 8.2k; R_0603_1608Metric; LCSC_PART C114637
R16, R17, R22: 10K; R_0603_1608Metric; LCSC_PART C25804
TP4, TP5, TP6, TP7: TestPoint; TestPoint_Pad_D1.0mm; not fitted
U5, U6, U7: HX711; SOP-16_3.9x9.9mm_P1.27mm; LCSC_PART C43656

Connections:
+3.3V: C15.1, C16.1, C17.1, C18.1, C20.1, C21.1, C29.1, C30.1, C32.1, Q1.2 (E), Q2.2 (E), Q3.2 (E), R16.2, R17.2, R22.2, U5.1 (VSUP), U5.16 (DVDD), U6.1 (VSUP), U6.16 (DVDD), U7.1 (VSUP), U7.16 (DVDD); also elsewhere on the board
/LOAD_CELL_1: TP5.1, U6.12 (DOUT); also elsewhere on the board
/LOAD_CELL_2: TP4.1, U5.12 (DOUT); also elsewhere on the board
/LOAD_CELL_3: TP7.1, U7.12 (DOUT); also elsewhere on the board
/LOAD_CELL_CLK: TP6.1, U5.11 (PD_SCK), U6.11 (PD_SCK), U7.11 (PD_SCK); also elsewhere on the board
/Load Cells/A1+: J17.5, R10.1
/Load Cells/A1-: J17.4, R11.2
/Load Cells/A2+: J19.5, R8.1
/Load Cells/A2-: J19.4, R9.2
/Load Cells/A3+: J18.5, R18.1
/Load Cells/A3-: J18.4, R19.2
/Load Cells/B1+: J17.2, U6.10 (INB+)
/Load Cells/B1-: J17.3, U6.9 (INB-)
/Load Cells/B2+: J19.2, U5.10 (INB+)
/Load Cells/B2-: J19.3, U5.9 (INB-)
/Load Cells/B3+: J18.2, U7.10 (INB+)
/Load Cells/B3-: J18.3, U7.9 (INB-)
GNDREF: C15.2, C16.2, C17.2, C18.2, C19.2, C20.2, C21.2, C22.2, C25.2, C26.2, C27.2, C28.2, C29.2, C30.2, C31.2, C32.2, C34.2, C35.2, J17.1, J17.6, J18.1, J18.6, J19.1, J19.6, JP1.1 (A), JP2.1 (A), JP3.1 (A), R13.2, R15.2, R21.2, U5.5 (AGND), U5.14 (XI), U6.5 (AGND), U6.14 (XI), U7.5 (AGND), U7.14 (XI); also elsewhere on the board
unnamed: C22.1, C26.1, J17.7, L2.1
unnamed: C31.1, C34.1, J18.7, L3.1
unnamed: C19.1, C25.1, J19.7, L1.1
unnamed: JP1.2 (B), R16.1, U5.15 (RATE)
unnamed: JP2.2 (B), R17.1, U6.15 (RATE)
unnamed: JP3.2 (B), R22.1, U7.15 (RATE)
unnamed: Q1.1 (B), U5.2 (BASE)
unnamed: L1.2, Q1.3 (C), R12.1, U5.3 (AVDD)
unnamed: Q2.1 (B), U6.2 (BASE)
unnamed: L2.2, Q2.3 (C), R14.1, U6.3 (AVDD)
unnamed: Q3.1 (B), U7.2 (BASE)
unnamed: L3.2, Q3.3 (C), R20.1, U7.3 (AVDD)
unnamed: C23.1, R8.2, U5.8 (INA+)
unnamed: C23.2, R9.1, U5.7 (INA-)
unnamed: C27.1, U5.6 (VBG)
unnamed: R12.2, R13.1, U5.4 (VFB)
unnamed: C24.1, R10.2, U6.8 (INA+)
unnamed: C24.2, R11.1, U6.7 (INA-)
unnamed: C28.1, U6.6 (VBG)
unnamed: R14.2, R15.1, U6.4 (VFB)
unnamed: C33.1, R18.2, U7.8 (INA+)
unnamed: C33.2, R19.1, U7.7 (INA-)
unnamed: C35.1, U7.6 (VBG)
unnamed: R20.2, R21.1, U7.4 (VFB)

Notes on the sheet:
HX711
SparkFun_HX711_Load_Cell_V11 Design by: N.Seidle License:CC BY-SA 4.0
E+ E- A+ A- B- B+ Shield
ANALOG SUPPLY CURRENT: 1400uA DIGITAL SUPPLY CURRENT: 100uA
Modifications: Merge the two input connectors in to one

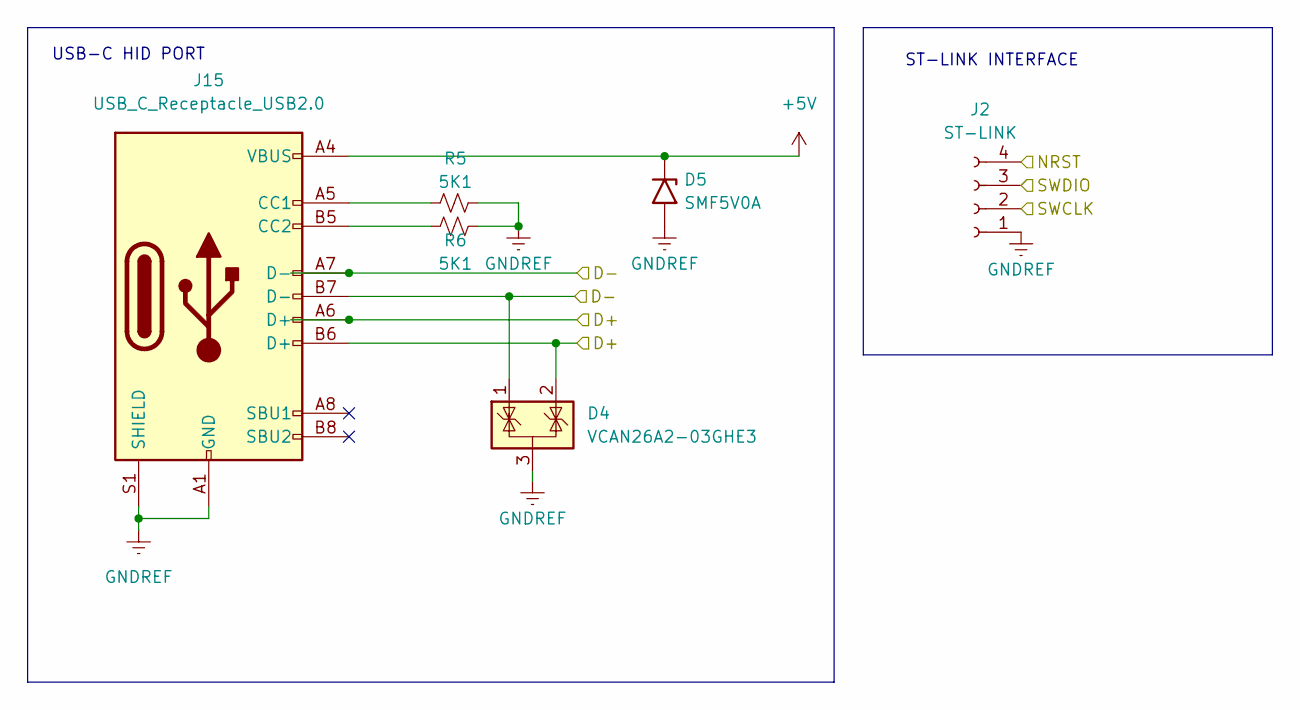
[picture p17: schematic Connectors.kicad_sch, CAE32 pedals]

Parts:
D4: VCAN26A2-03GHE3; SOT-323_SC-70; LCSC_PART C413455
D5: SMF5V0A; D_SOD-123; LCSC_PART C908213
J2: ST-LINK; PinSocket_1x04_P2.54mm_Vertical
J15: USB_C_Receptacle_USB2.0; USB_C_Receptacle_HRO_TYPE-C-31-M-12
R5, R6: 5K1; R_0603_1608Metric

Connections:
+5V: D5.1 (A1), J15.A4 (VBUS), J15.A9 (VBUS), J15.B4 (VBUS), J15.B9 (VBUS); also elsewhere on the board
/D+: D4.2 (K), J15.A6 (D+), J15.B6 (D+); also elsewhere on the board
/D-: D4.1 (K), J15.A7 (D-), J15.B7 (D-); also elsewhere on the board
/NRST: J2.4; also elsewhere on the board
/SWCLK: J2.2; also elsewhere on the board
/SWDIO: J2.3; also elsewhere on the board
GNDREF: D4.3 (A), D5.2 (A2), J2.1, J15.A1 (GND), J15.A12 (GND), J15.B1 (GND), J15.B12 (GND), J15.S1 (SHIELD), R5.2, R6.2; also elsewhere on the board
unnamed: J15.A5 (CC1), R5.1
unnamed: J15.B5 (CC2), R6.1

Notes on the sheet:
USB-C HID PORT
ST-LINK INTERFACE

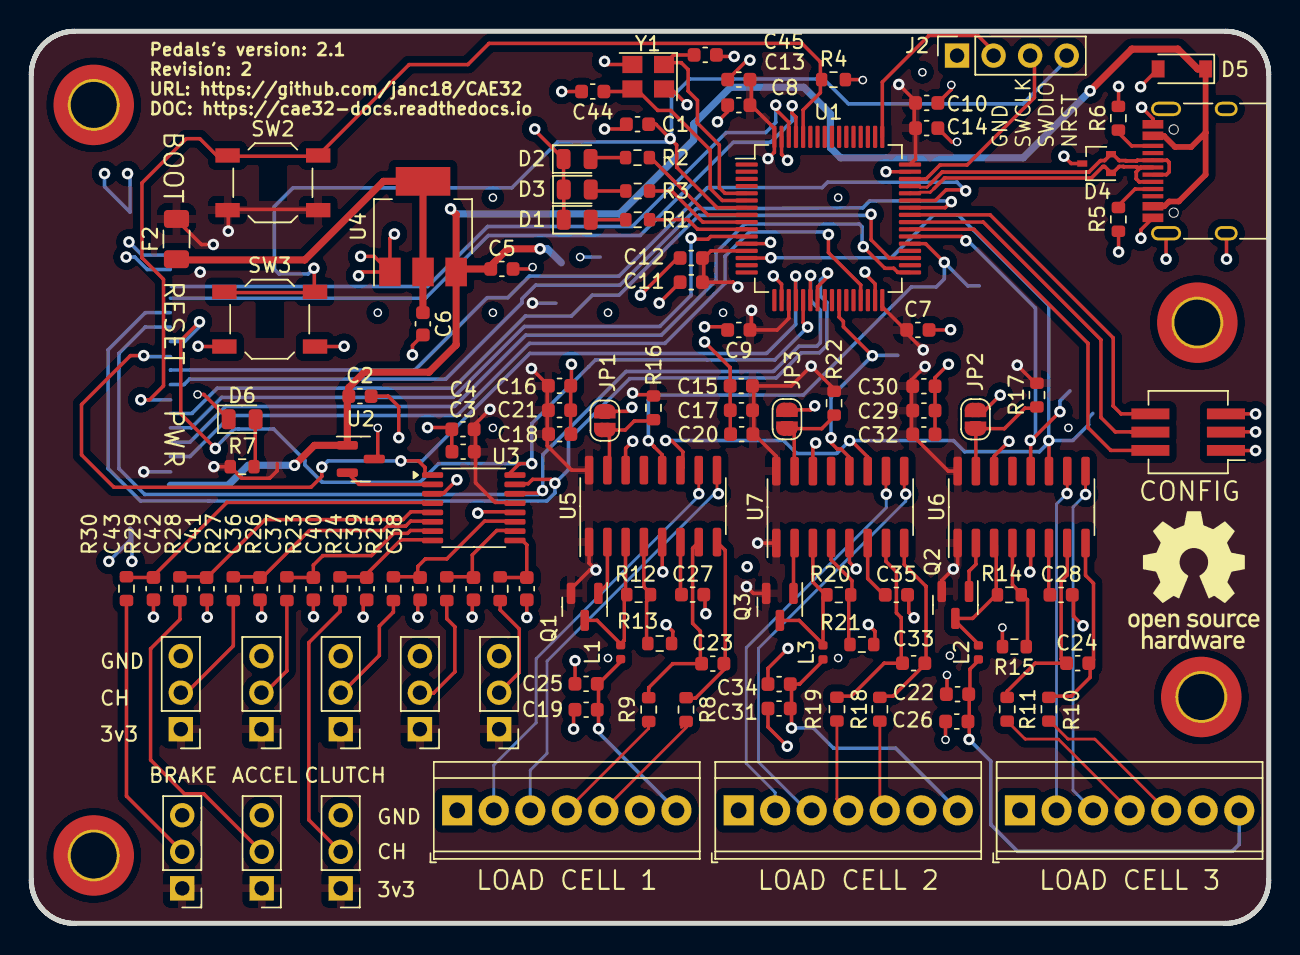
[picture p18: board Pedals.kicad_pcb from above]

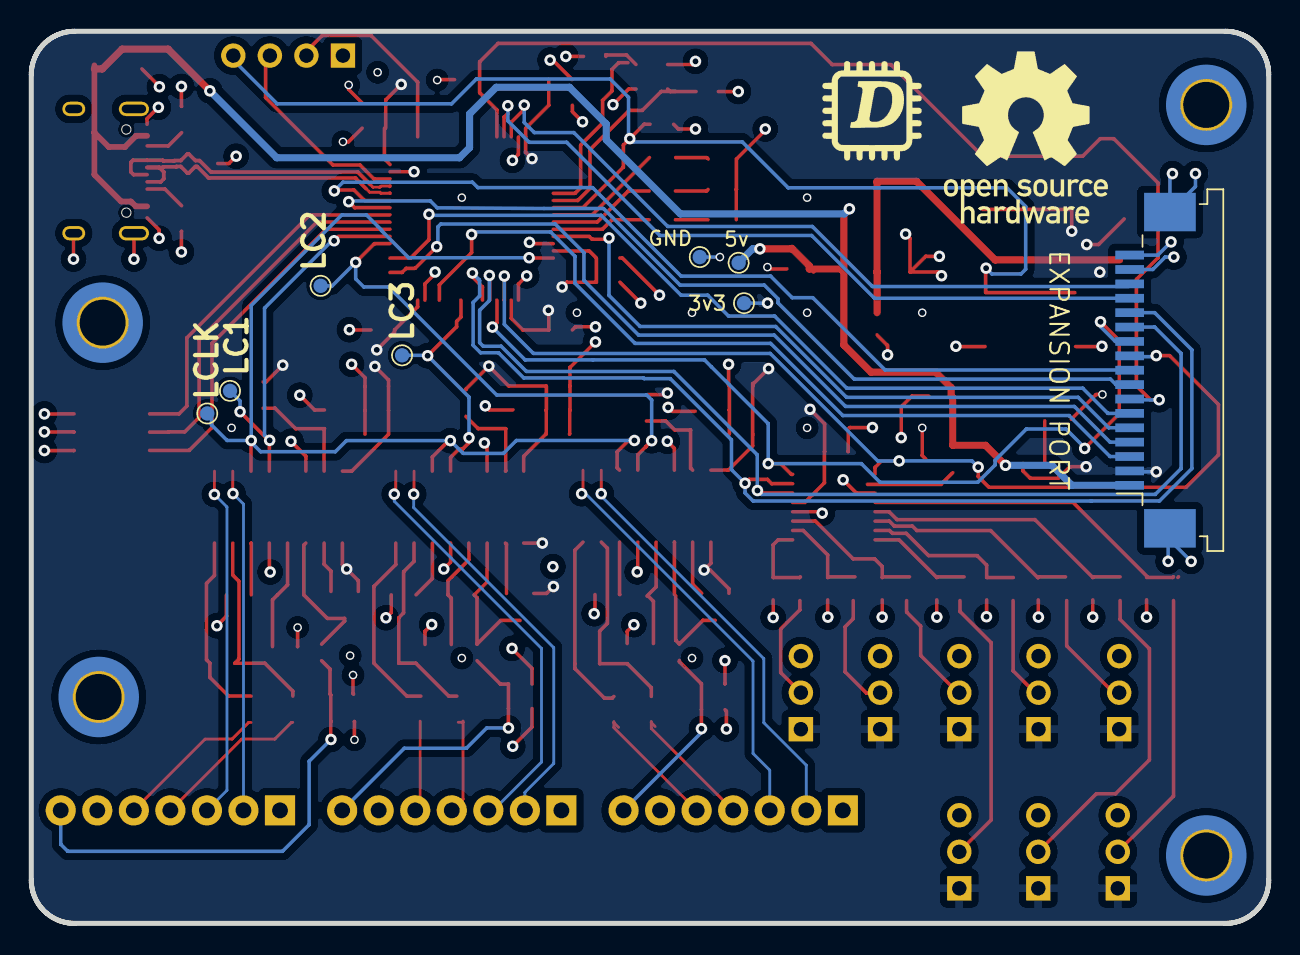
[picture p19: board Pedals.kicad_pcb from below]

Board: 4 copper layers, 86.0 x 62.0 mm, 127 parts (8 on the bottom side), 93 nets.

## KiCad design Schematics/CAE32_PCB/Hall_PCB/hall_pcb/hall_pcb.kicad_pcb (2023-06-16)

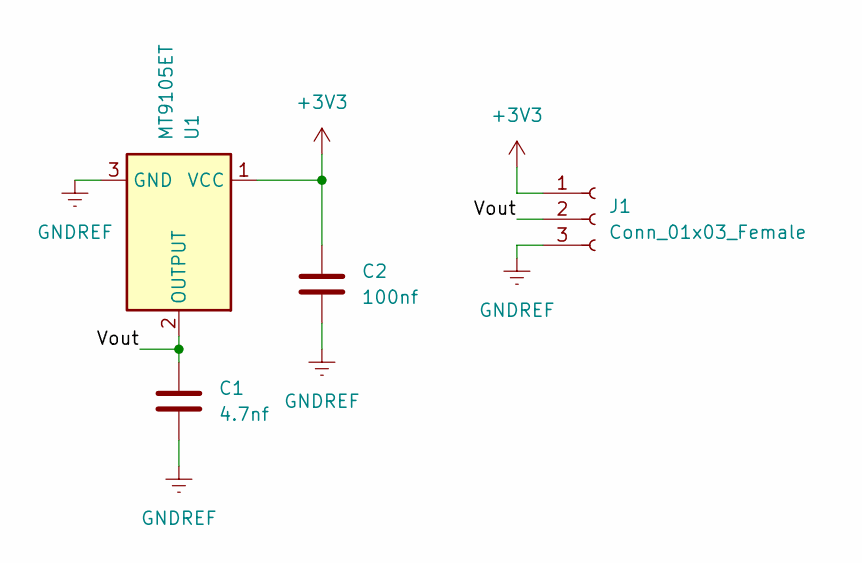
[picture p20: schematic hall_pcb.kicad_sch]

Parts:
C1: 4.7nf; C_0805_2012Metric_Pad1.18x1.45mm_HandSolder
C2: 100nf; C_0805_2012Metric_Pad1.18x1.45mm_HandSolder
J1: Conn_01x03_Female; JST_EH_B3B-EH-A_1x03_P2.50mm_Vertical
U1: MT9105ET; SOT-23

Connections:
+3V3: C2.1, J1.1, U1.1 (VCC)
/Vout: C1.1, J1.2, U1.2 (OUTPUT)
GNDREF: C1.2, C2.2, J1.3, U1.3 (GND)

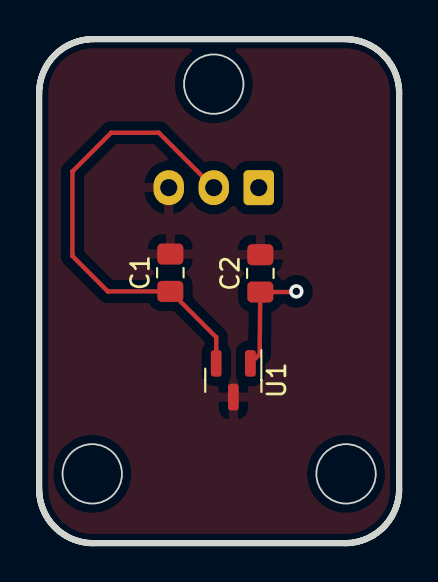
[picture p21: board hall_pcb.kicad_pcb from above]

Board: 2 copper layers, 20.0 x 28.0 mm, 4 parts (1 on the bottom side), 3 nets.

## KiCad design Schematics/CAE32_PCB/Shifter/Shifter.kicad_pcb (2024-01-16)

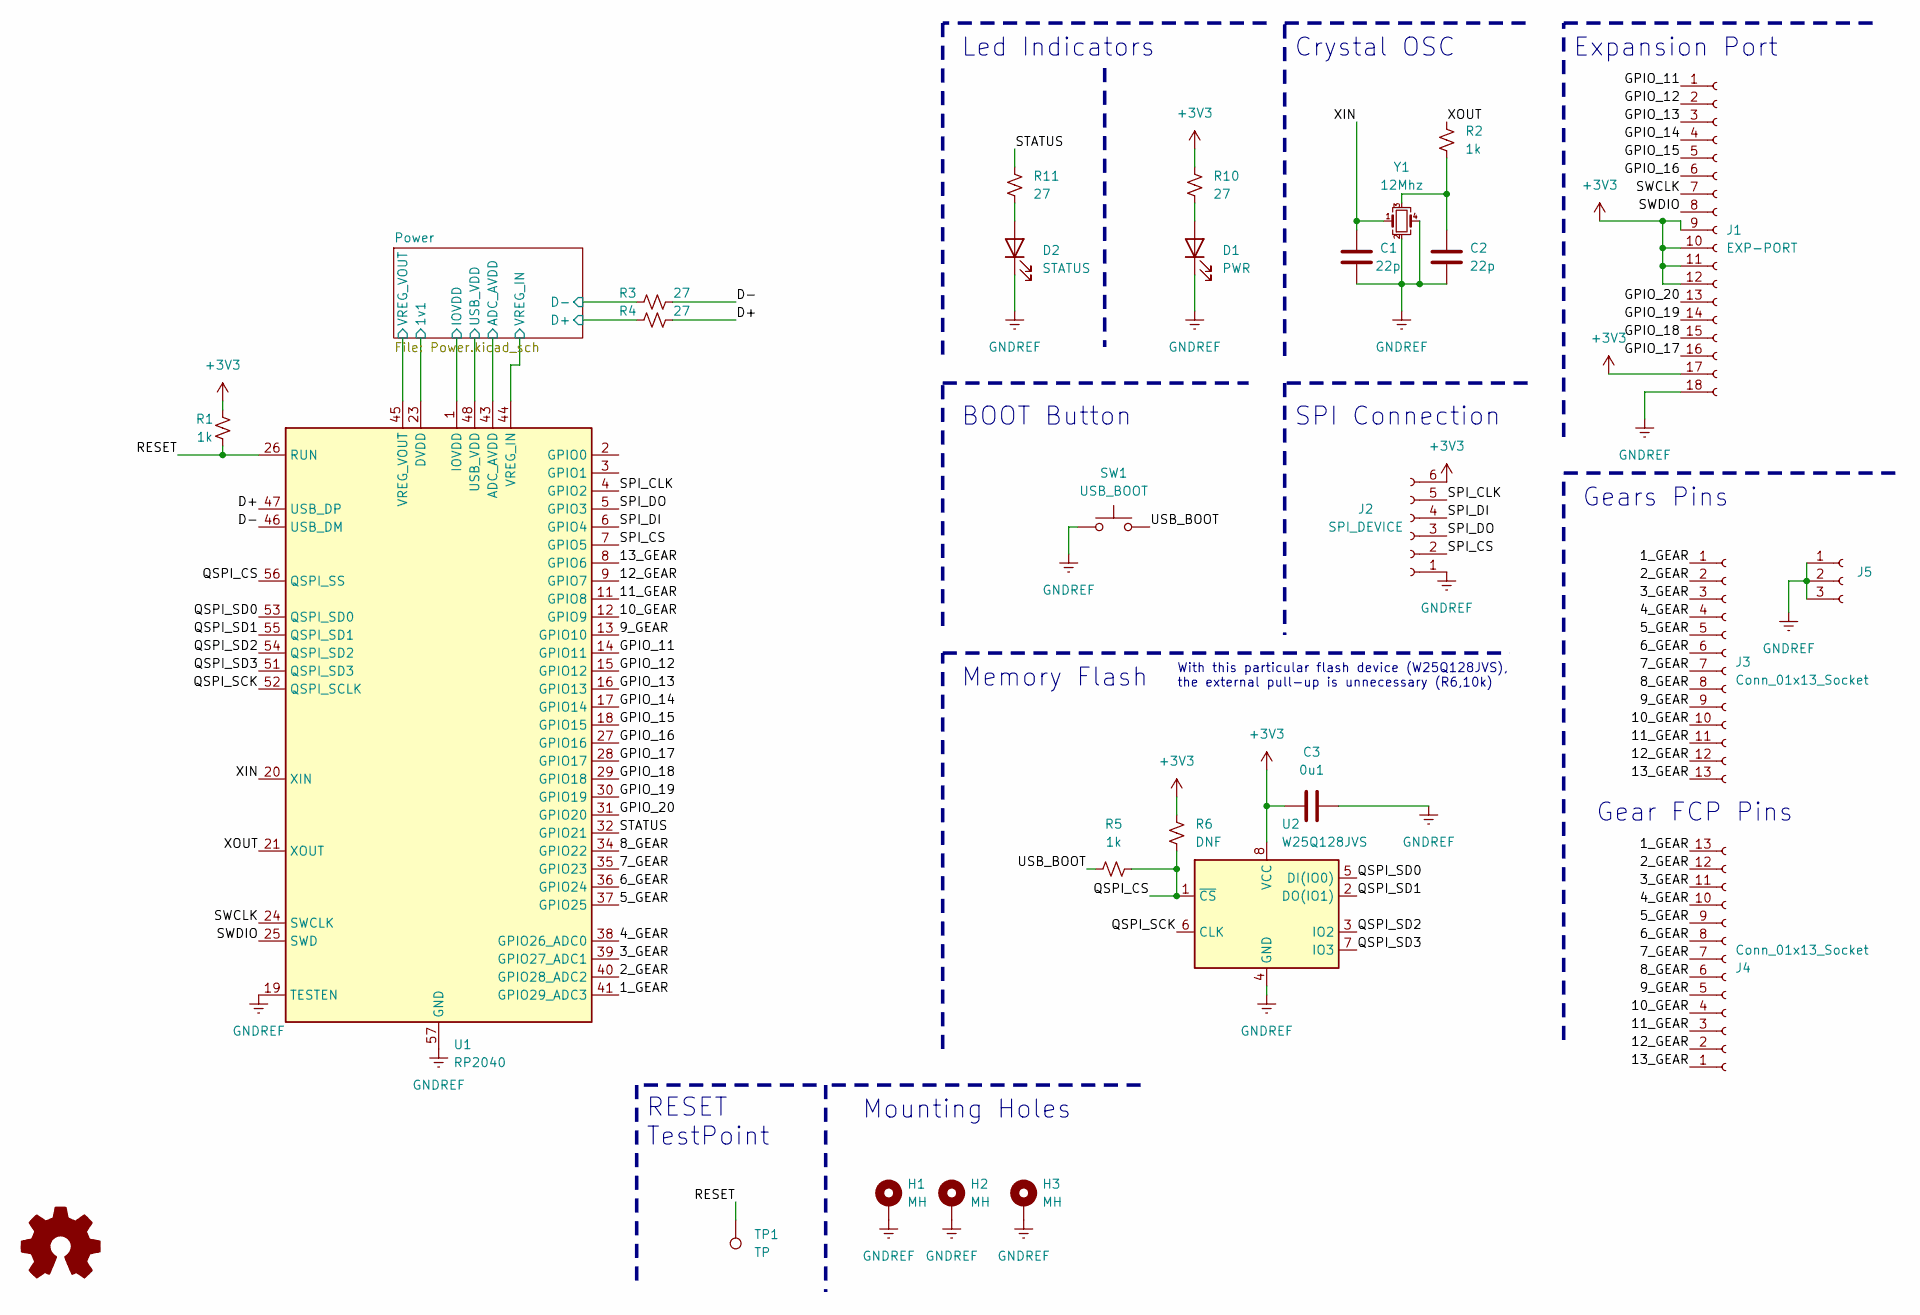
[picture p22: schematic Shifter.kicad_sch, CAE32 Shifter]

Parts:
C1, C2: 22p; C_01005_0402Metric
C3: 0u1; C_01005_0402Metric
D1: PWR; LED_0402_1005Metric
D2: STATUS; LED_0402_1005Metric
H1, H2, H3: MH; MountingHole_2.7mm_M2.5_Pad_Via
J1: EXP-PORT; Hirose_FH12-18S-0.5SH_1x18-1MP_P0.50mm_Horizontal
J2: SPI_DEVICE; PinSocket_2x03_P2.54mm_Vertical
J3: Conn_01x13_Socket; Pad_1x13_THT_1.27mm
J4: Conn_01x13_Socket; Hirose_FH12-13S-0.5SH_1x13-1MP_P0.50mm_Horizontal
J5: Conn_01x03_Socket; PinHeader_1x03_P2.54mm_Vertical
R1, R2, R5: 1k; R_0402_1005Metric
R3, R4, R10, R11: 27; R_0402_1005Metric
R6: DNF; R_0402_1005Metric
SW1: USB_BOOT; SW_Push_SPST_NO_Alps_SKRK
TP1: TP; TestPoint_Pad_D1.0mm
U1: RP2040; QFN-56-1EP_7x7mm_P0.4mm_EP3.2x3.2mm
U2: W25Q128JVS; SOIC-8_5.23x5.23mm_P1.27mm
Y1: 12Mhz; Crystal_SMD_3225-4Pin_3.2x2.5mm

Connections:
+3V3: C3.1, J1.9, J1.10, J1.11, J1.12, J1.17, J2.6, R1.1, R6.2, R10.1, U1.1 (IOVDD), U1.10 (IOVDD), U1.22 (IOVDD), U1.33 (IOVDD), U1.42 (IOVDD), U1.43 (ADC_AVDD), U1.44 (VREG_IN), U1.45 (VREG_VOUT), U1.48 (USB_VDD), U1.49 (IOVDD), U2.8 (VCC); also elsewhere on the board
/1_GEAR: J3.1, J4.13, U1.41 (GPIO29_ADC3)
/2_GEAR: J3.2, J4.12, U1.40 (GPIO28_ADC2)
/3_GEAR: J3.3, J4.11, U1.39 (GPIO27_ADC1)
/4_GEAR: J3.4, J4.10, U1.38 (GPIO26_ADC0)
/5_GEAR: J3.5, J4.9, U1.37 (GPIO25)
/6_GEAR: J3.6, J4.8, U1.36 (GPIO24)
/7_GEAR: J3.7, J4.7, U1.35 (GPIO23)
/8_GEAR: J3.8, J4.6, U1.34 (GPIO22)
/9_GEAR: J3.9, J4.5, U1.13 (GPIO10)
/10_GEAR: J3.10, J4.4, U1.12 (GPIO9)
/11_GEAR: J3.11, J4.3, U1.11 (GPIO8)
/12_GEAR: J3.12, J4.2, U1.9 (GPIO7)
/13_GEAR: J3.13, J4.1, U1.8 (GPIO6)
/D+: R4.1, U1.47 (USB_DP)
/D-: R3.1, U1.46 (USB_DM)
/GPIO_11: J1.1, U1.14 (GPIO11)
/GPIO_12: J1.2, U1.15 (GPIO12)
/GPIO_13: J1.3, U1.16 (GPIO13)
/GPIO_14: J1.4, U1.17 (GPIO14)
/GPIO_15: J1.5, U1.18 (GPIO15)
/GPIO_16: J1.6, U1.27 (GPIO16)
/GPIO_17: J1.16, U1.28 (GPIO17)
/GPIO_18: J1.15, U1.29 (GPIO18)
/GPIO_19: J1.14, U1.30 (GPIO19)
/GPIO_20: J1.13, U1.31 (GPIO20)
/Power/1v1: U1.23 (DVDD), U1.50 (DVDD); also elsewhere on the board
/Power/D+: R4.2; also elsewhere on the board
/Power/D-: R3.2; also elsewhere on the board
/QSPI_CS: R5.2, R6.1, U1.56 (QSPI_SS), U2.1 (~CS)
/QSPI_SCK: U1.52 (QSPI_SCLK), U2.6 (CLK)
/QSPI_SD0: U1.53 (QSPI_SD0), U2.5 (DI(IO0))
/QSPI_SD1: U1.55 (QSPI_SD1), U2.2 (DO(IO1))
/QSPI_SD2: U1.54 (QSPI_SD2), U2.3 (IO2)
/QSPI_SD3: U1.51 (QSPI_SD3), U2.7 (IO3)
/RESET: R1.2, TP1.1, U1.26 (RUN)
/SPI_CLK: J2.5, U1.4 (GPIO2)
/SPI_CS: J2.2, U1.7 (GPIO5)
/SPI_DI: J2.4, U1.6 (GPIO4)
/SPI_DO: J2.3, U1.5 (GPIO3)
/STATUS: R11.1, U1.32 (GPIO21)
/SWCLK: J1.7, U1.24 (SWCLK)
/SWDIO: J1.8, U1.25 (SWD)
/USB_BOOT: R5.1, SW1.2
/XIN: C1.1, U1.20 (XIN), Y1.1
/XOUT: R2.1, U1.21 (XOUT)
GNDREF: C1.2, C2.2, C3.2, D1.1 (K), D2.1 (K), H1.1, H2.1, H3.1, J1.18, J2.1, J5.1, J5.2, J5.3, SW1.1, U1.19 (TESTEN), U1.57 (GND), U2.4 (GND), Y1.2, Y1.4; also elsewhere on the board
unnamed: C2.1, R2.2, Y1.3
unnamed: D1.2 (A), R10.2
unnamed: D2.2 (A), R11.2

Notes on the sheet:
Expansion Port
Crystal OSC
BOOT Button
Memory Flash
With this particular flash device (W25Q128JVS), the external pull-up is unnecessary (R6,10k)
Gears Pins
SPI Connection
Mounting Holes
Led Indicators
RESET TestPoint
Gear FCP Pins

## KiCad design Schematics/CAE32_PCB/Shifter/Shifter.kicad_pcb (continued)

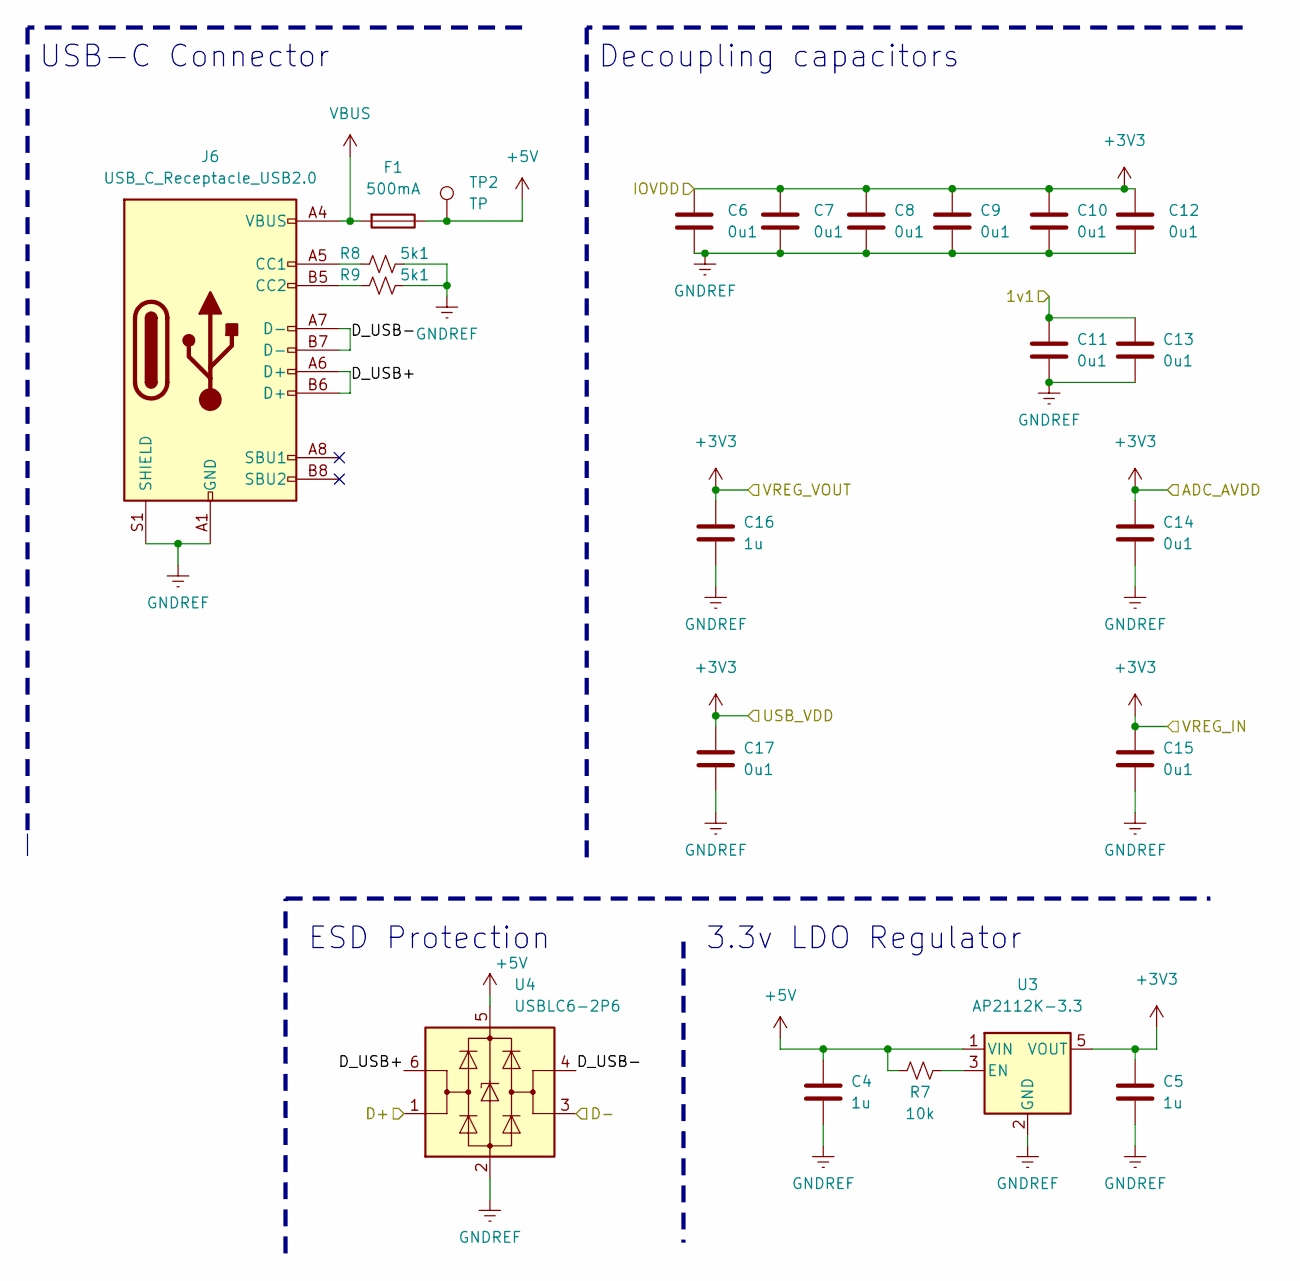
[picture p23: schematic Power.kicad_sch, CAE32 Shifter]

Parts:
C4, C5, C16: 1u; C_01005_0402Metric
C6, C7, C8, C9, C10, C11, C12, C13, C14, C15, C17: 0u1; C_01005_0402Metric
F1: 500mA; Fuse_0603_1608Metric
J6: USB_C_Receptacle_USB2.0; USB_C_Receptacle_Palconn_UTC16-G
R7: 10k; R_0402_1005Metric
R8, R9: 5k1; R_0402_1005Metric
TP2: TP; TestPoint_Pad_D1.0mm
U3: AP2112K-3.3; SOT-23-5
U4: USBLC6-2P6; SOT-666

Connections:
+3V3: C5.1, C6.1, C7.1, C8.1, C9.1, C10.1, C12.1, C14.1, C15.1, C16.1, C17.1, U3.5 (VOUT); also elsewhere on the board
+5V: C4.1, F1.1, R7.2, TP2.1, U3.1 (VIN), U4.5 (VBUS)
/Power/1v1: C11.1, C13.1; also elsewhere on the board
/Power/D+: U4.1 (I/O1); also elsewhere on the board
/Power/D-: U4.3 (I/O2); also elsewhere on the board
/Power/D_USB+: J6.A6 (D+), J6.B6 (D+), U4.6 (I/O1)
/Power/D_USB-: J6.A7 (D-), J6.B7 (D-), U4.4 (I/O2)
GNDREF: C4.2, C5.2, C6.2, C7.2, C8.2, C9.2, C10.2, C11.2, C12.2, C13.2, C14.2, C15.2, C16.2, C17.2, J6.A1 (GND), J6.A12 (GND), J6.B1 (GND), J6.B12 (GND), J6.S1 (SHIELD), R8.1, R9.1, U3.2 (GND), U4.2 (GND); also elsewhere on the board
unnamed: J6.A5 (CC1), R8.2
unnamed: J6.B5 (CC2), R9.2
unnamed: R7.1, U3.3 (EN)
VBUS: F1.2, J6.A4 (VBUS), J6.A9 (VBUS), J6.B4 (VBUS), J6.B9 (VBUS)

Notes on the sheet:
USB-C Connector
3.3v LDO Regulator
ESD Protection
Decoupling capacitors

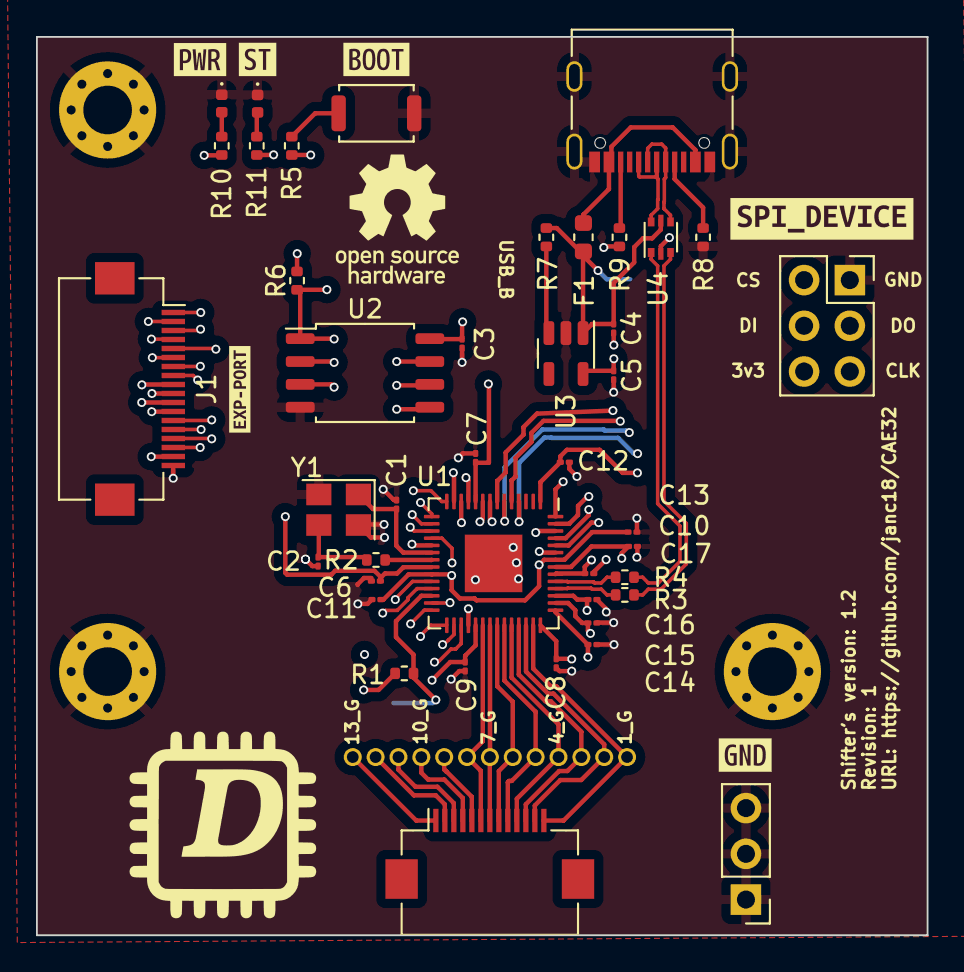
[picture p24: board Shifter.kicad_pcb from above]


Board: 4 copper layers, 49.5 x 49.9 mm, 56 parts (4 on the bottom side), 57 nets.

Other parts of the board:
kibuzzard-64B75D82: G***; kibuzzard-64B75D82
kibuzzard-64B759C0: G***; kibuzzard-64B759C0
kibuzzard-6511E845: G***; kibuzzard-6511E845
kibuzzard-6511E886: G***; kibuzzard-6511E886
kibuzzard-6517AD32: G***; kibuzzard-6517AD32
kibuzzard-6518B6F6: G***; kibuzzard-6518B6F6
kibuzzard-651234A4: G***; kibuzzard-651234A4
kibuzzard-651234C4: G***; kibuzzard-651234C4

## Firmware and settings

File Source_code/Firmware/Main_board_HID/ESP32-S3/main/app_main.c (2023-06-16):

#include "Spi_communication.h"
#include "Usb_communication.h"
#include "Wheel_task.h"
#include "driver/gpio.h"
#include "esp_log.h"
#include "freertos/task.h"
#include <stdio.h>

Raw_pedals_value pedals_t = {0};

void app_main() {
    Raw_pedals_value *p_pedals_t = malloc(sizeof(pedals_t));
    p_pedals_t = &pedals_t;

    p_pedals_t->spi = init_spi_device();
    printf("%p\n", p_pedals_t);
    usb_initialization();
    Create_tasks(p_pedals_t);
}
// https://github.com/hathach/tinyusb/blob/c0d79457f61cc4ee27336f430a6f96403bd8b289/src/class/hid/hid_device.h
/*
            static bool send_hid_data = true;
            if (send_hid_data) {
                for (int i = 0; i < 100; i++) {

            send_hid_data = !gpio_get_level(APP_BUTTON);
            */

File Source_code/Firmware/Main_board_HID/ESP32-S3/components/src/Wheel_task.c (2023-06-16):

#include "Wheel_task.h"
#include "Spi_communication.h"
#include "Usb_communication.h"

void print(void *Pvparameters) {

    Raw_pedals_value *pedals_values = NULL;
    pedals_values = (Raw_pedals_value *)Pvparameters;
    TickType_t xLastWakeTime = xTaskGetTickCount();
    while (1) {
        printf("%d\t,%d\t,%d\n", pedals_values->Clutch_value, pedals_values->Brake_value,
               pedals_values->Accelerator_value);
        vTaskDelayUntil(&xLastWakeTime, 20 / portTICK_PERIOD_MS);
    }
}
void Create_tasks(Raw_pedals_value *p_pedals_t) {
    xTaskCreate(Get_raw_pedals_value, "Pedals", 4000, (void *)p_pedals_t, 2, NULL);
    xTaskCreate(Send_custom_hid, "Send HID Report", 3000, (void *)p_pedals_t, 1, NULL);
    xTaskCreate(print, "print", 3000, (void *)p_pedals_t, 1, NULL);
}
void Get_raw_pedals_value(void *Pvparameters) {
    Raw_pedals_value *pedals_values = NULL;
    pedals_values = (Raw_pedals_value *)Pvparameters;
    printf("%p\n", pedals_values);
    TickType_t xLastWakeTime = xTaskGetTickCount();
    while (1) {
        uint8_t tx_buffer[1] = {0x11};
        uint8_t rx_buffer[3] = {0};
        spi_transaction_t t;
        memset(&t, 0, sizeof(t));
        t.length = 8 * 4;
        t.tx_buffer = tx_buffer;
        t.rx_buffer = rx_buffer;
        spi_device_polling_transmit(pedals_values->spi, &t);
        pedals_values->Accelerator_value = rx_buffer[0];
        pedals_values->Brake_value = rx_buffer[1];
        pedals_values->Clutch_value = rx_buffer[2];
        // spi_device_transmit(pedals_values->spi, &t);
        vTaskDelayUntil(&xLastWakeTime, 70 / portTICK_PERIOD_MS);
    }

    /*
        TickType_t xLastWakeTime = xTaskGetTickCount();
        while (1) {
            printf("1O1\n");
            vTaskDelayUntil(&xLastWakeTime, 1900 / portTICK_PERIOD_MS);
        }
    */
}

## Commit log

2023-06-16 Primer commit
    [ADC.kicad_sch, EVQPUM02K-Part.step, EVQPUM02K.FCStd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]
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2023-06-17 add: Archivo docker para la construcción de GUI con GTK3 y cmake
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2023-06-17 update: cambio de nombre de versión de docker de cae32_image a cae32/bullseye:1.0
2023-06-17 update: README, con las nuevas caracteristicas de la PCB de pedales version
2023-06-17 add: nueva hoja de esquematicos para añadir los componentes necesarios relacionados a conectores de: usb, programacion y debugging
    [Connectors.kicad_sch]
2023-06-17 chore: se corrigen valores de referencias de componentes, creación de nuevas hojas de diagramas, mejor distribución de componentes
    [ADC.kicad_sch, Pedals.kicad_pcb, Pedals.kicad_sch]
2023-06-17 update: se agrega la opcion --rm para remover el contenedor cuando termine de construir la gui
2023-06-17 add: hoja de esquematicos de conexiones de alimentacion
    [Power.kicad_sch]
2023-06-17 update: Primera revision de etapa ADC lista, ademas de una mejor distrubucion de componentes
    [ADC.kicad_sch, Connectors.kicad_sch, Pedals.kicad_pcb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]
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2023-06-18 add: hoja de equematicos para las celdas de carga
    [Load_cells.kicad_sch]
2023-06-18 update: se añade otra hoja para las celdas de carga, ademas de reorganizar todas las hojas
    [ADC.kicad_sch, Connectors.kicad_sch, Pedals.kicad_pcb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]
2023-06-18 update: se agrega instrucciones para la compilacion de la GUI usando docker
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2023-06-19 update: Componentes acomodados en la PCB
    [ADC.kicad_sch, Connectors.kicad_sch, Load_cells.kicad_sch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]
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2023-06-20 chore: cambio de nombre de proyecto (ESP32S3 -> cae_esp32s3) y se incluye el directorio de components
2023-06-20 fix: se corrige el nombre de la depencia en require de tinyusb->esp_tinyusb, ademas de añadir las depencia de freertos
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2023-06-20 chore: se corrige el estilo de codigo
2023-06-20 fix: se corrige la ruta de include
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2023-06-21 update: se agrega el consumo de corriente a los IC's ademas de agregar el URL y numero de parte de los componentes de LCSC en kicad
    [ADC.kicad_sch, Connectors.kicad_sch, Load_cells.kicad_sch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]
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2023-06-21 update: README.md con referencia a como contribuir con el proyecto en ingles y español
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2023-06-22 Update: esquematicos de PCB, reorganizando elementos para hacer mas compacta la pcb, ademas de agregar serigrafia e imagenes de la PCB
    [Connectors.kicad_sch, Load_cells.kicad_sch, Pedals.kicad_pcb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]
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2023-06-25 update: se crea la primera revisión de la PCB
    [ADC.kicad_sch, Connectors.kicad_sch, Load_cells.kicad_sch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]
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2023-06-25 add: se añade un fusible extra para proteger el circuito de 5v al regulador de voltage de 3v3
    [Connectors.kicad_sch, Pedals.kicad_pcb]
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2023-06-26 update: se agrega via stitching a la pcb de los pedales
    [Pedals.kicad_pcb]
2023-06-28 fix: ruta de modelos 3D, a una ruta relativa
    [Pedals.kicad_pcb, TS-1095PD-A16B2-D2-Part.step, TS-1095PD-A16B2-D2.FCStd]
2023-07-12 add: plantilla para diseño de pcb para shifter
    [Connectors.kicad_sch, Load_cells.kicad_sch, Pedals.kicad_pcb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]
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2023-07-16 delete: archivo BOM
    [Pedals.csv]
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2023-07-16 add: diseño de esquemático básico usando el microcontrolador rp2040
    [Shifter.kicad_pcb, Shifter.kicad_sch]
2023-07-21 update: se enruta completamente la pcb, aunque aun necesario un análisis posterior, ademas de agregar huellas e imagen de la pcb completa
    [Power.kicad_sch, Shifter.kicad_pcb, Shifter.kicad_sch]
2023-09-04 update:Shifter PCB v1.1 Revision 1: Se cambia la posición de los "castelladed pins" a un solo lado, aumentando un poco el tamaño de la pcb pero reduciendo el costo de manufactura, ademas se añade la 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
    [Power.kicad_sch, Shifter.kicad_pcb, Shifter.kicad_sch]
2023-09-04 update: Se añade nombre y se separa a los diferentes componentes por categoria en el esquematico
    [Power.kicad_sch, Shifter.kicad_pcb, Shifter.kicad_sch]
2023-09-16 update: changed the castelled holes for pin sockets and changed 0603 footprints to 0402
    [Power.kicad_sch, Shifter.kicad_pcb, Shifter.kicad_sch]
2023-09-20 delete: removed Modular PCB folder and files
    [Modular.csv, Modular.kicad_pcb, Modular.kicad_sch]
2023-09-20 update: added templates files for the devolpment of a Feedback PCB
    [Steering_Wheel_FFB.kicad_pcb, Steering_Wheel_FFB.kicad_sch, cutOutPcb-Shape2DView.dxf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]
2023-09-20 chore: arrange schematics components
    [ADC.kicad_sch, Connectors.kicad_sch, Load_cells.kicad_sch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]
2023-09-20 chore: arrange of schematic elements
    [Power.kicad_sch, Shifter.kicad_pcb, Shifter.kicad_sch]
2023-09-24 update: change PCB for 2 layers to 4 layers
    [Steering_Wheel_FFB.kicad_pcb]
2023-09-24 update: new desing for the PCB edgecuts
    [cutOutPcb-Shape2DView.dxf, cutOutPcb.FCStd]
2023-09-24 add: included new dxf file with another desing for the cut out for the PCB
    [simcube.dxf]
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2023-09-27 update: added minor improvements to Pedal's PCB
    [ADC.kicad_sch, Load_cells.kicad_sch, Pedals.kicad_pcb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]
2023-09-27 update: added minor improvements to Shifter's PCB
    [Power.kicad_sch, Shifter.kicad_pcb, Shifter.kicad_sch]
2023-10-01 update: redesign of the shifter PCB, changing the PCB requirements(via from 0.15 to 0.3mm) and pin sockets for FCP connectors
    [Shifter.kicad_pcb, Shifter.kicad_sch]
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2023-12-01 chore: added two new "Section" with a brief function resume and a Pcb issues
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2023-12-25 fix: cmake device descriptor paths
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2024-01-13 update: PCB pedals Version:2.1.1
    [ADC.kicad_sch, Connectors.kicad_sch, Load_cells.kicad_sch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]
2024-01-16 chore: Moved all the Pedals contents a folder above and updated pcb including the required oscilator
    [ADC.kicad_sch, Connectors.kicad_sch, Load_cells.kicad_sch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]
2024-01-16 chore: update the schematics to the 7.0 kicad version
    [Shifter.kicad_pcb, Steering_Wheel_FFB.kicad_sch]
2024-01-16 rename: Esquematicos->Schematics folder
    [ADC.kicad_sch, Connectors.kicad_sch, EVQPUM02K-Part.step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]
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2024-02-05 fix: function print_contents_of_n_objects, now receive lines_tokenize struct, to avoid reading outside of token array
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2024-03-01 fix: changed target system to search for a device from usb to hid
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2024-03-09 fix: changed prototype function(search_device) now return a char * with the path of the actual searching device
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2024-03-09 fix: change search device function, now return a string with the correct path of the device
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2024-06-03 fixed: It can detected when is the device has been disconnected
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2024-08-09 update: now display correctly the device current events in the terminal
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2024-08-18 chore: added error message when the threads are created
2024-09-01 updated: Pcb design, fixed plane grounds and minor improvements, added stlink connector, updated BOM with the current market stock
    [ADC.kicad_sch, Connectors.kicad_sch, Load_cells.kicad_sch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]
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2024-10-01 fixed: changed fuse footprint for the correct one(0805)
    [Pedals.kicad_pcb, Power.kicad_sch]
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2024-10-26 fixed: changed fuse footprint to 1206
    [Pedals.kicad_pcb, Power.kicad_sch]
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2025-02-09 chore: fixed print format
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2025-04-19 fixed: SPI route
    [ADC.kicad_sch, Connectors.kicad_sch, Load_cells.kicad_sch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]
2025-07-05 fixed: SPI route and updated kicad versions in schematic and pcb design
    [ADC.kicad_sch, Connectors.kicad_sch, Load_cells.kicad_sch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]
2025-07-05 fixed: adc128 pin spacing
2025-07-20 fixed: report descriptor issue when map as throttle
